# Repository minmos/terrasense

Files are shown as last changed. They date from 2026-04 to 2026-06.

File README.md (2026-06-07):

### Quick Overview
* **`firmware`**: contains the esp-idf firmware running on the esp32c6
* **`cad`**: contains the CAD files for the case housing the sockets, the 12V PSU, the relais/hv pcb, and an extension for that box housing the main pcb
* **`pcb`**: contains the KiCad files for the relais/hv pcb as well as the main pcb

### DEMO
Here is a quick demo video of our Terrasense implementation in action:

https://github.com/user-attachments/assets/7964f494-83c7-4bb1-9dd9-c3dd94d3becd

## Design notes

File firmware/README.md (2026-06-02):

# TerraSense

TerraSense is a smart-terrarium controller built on the ESP32-C6. It provides Home Assistant integration via MQTT to control the environment.

---

## Hardware Requirements/Features
* **Home Assistant Integration:** Uses MQTT Auto-Discovery for all peripherals for Home Assistant integration.
* **Custom PCB:** We used a custom PCB to keep everything clean
* **Sensor Support:**
  * **I²C:** SHT35 series (Temperature & Humidity) via multiplexer(TCA9548A).
  * **OneWire:** DS18B20.
  * **Binary:** Binary liquid level sensor(XKC-Y25-NPN).
* **Actuator Support:**
  * **GPIO:** GPIO relays and Solid State Relays (SSR) for heaters, lights, and misting pumps.
  * **Fans:** supporting 3 and 4 pin fans

---

## Wiring & Pinout

The hardware configuration as defined in `sys_config.h`. 

| Interface | Component / Name | ESP32-C6 Pin | Notes |
| :--- | :--- | :--- | :--- |
| **I²C Bus** | SDA / SCL | GPIO 5 / GPIO 6 | up to 6 SHT35 sensors supported by I²C Mux |
| **OneWire** | DS18B20 Probe | GPIO 4 | up to 8 DS18B20 sensors |
| **Binary** | Liquid Level Sensor | GPIO 11 | - |
| **GPIO Output** | 4 230V Relais(one SSR) | GPIO 7/0/1/10 | - |
| **Fan** | either MOSFET or PWM | GPIO 18-23 | two fan connectors on pcb |

*(Note: Every pin assignment, default state, and active-high/low logic can be customized in `sys_config.h`.)*

---

## Installation & Setup

### 1. Prerequisites
Ensure you have the [ESP-IDF framework](https://docs.espressif.com/projects/esp-idf/en/latest/esp32/get-started/) installed and configured on your machine.

### 2. Setup
Depending on where your ESP-IDF is installed run the following to activate ESP-IDF environment:
```bash
. $HOME/.espressif/tools/activate_idf_v6.0.sh
```
Before touching any configrations, we need to set network and MQTT broker specifics by running the following command in the root dir of our project:
```bash
idf.py menuconfig
```
### 3. Configuration
Before compiling, open `/components/sys_config/include/sys_config.h` to define the specific setup.
* **MQTT Topics:** Set `MQTT_DOMAIN_PREFIX` and `TERRARIUM_ID` which are used by macros for the topics.
* **Enable/Disable Hardware:** See the [Hardware Configuration](#hardware-configuration) section.
* **Logic Implementation:** `components/app_logic/app_logic.c` is used to define the control logic.

### 4. Build and Flash
Run the standard ESP-IDF commands to compile and flash to your board(either through terminal with `idf.py` commands or through VsCode buttons).

---

## OTA Update Support

The device supports OTA updates triggered via MQTT by publishing the location of the new binary to `<your_mqtt_base_topic>/cmd/update`.

### To locally test OTA updates

Build the project normally. Navigate to the build folder and start a temporary HTTP server(here just a tiny ruby server available under localhost:8070):

```bash
cd build
ruby -run -e httpd . -p 8070
```
The payload then looks like this:
```text
http://<your_ip>:8070/firmware.bin
```

# Hardware Configuration

Hardware and pin configurations are defined in `components/sys_config/include/sys_config.h`. We provide struct for all configurable peripherals of this project which are explained in more detail.
To keep MQTT topics somewhat consistent, we have define an MQTT scheme in `components/sys_config/mqtt_namingscheme.md`. One only has to define `MQTT_DOMAIN_PREFIX`, `TERRARIUM_ID` and the respective sensor and actuator structs. Everything else is handled by the implementation.

> If one wishes to change or extend the MQTT autodiscovery logic, one could define it through `components/app_logic/app_logic.c` and `components/net_mqtt/hass_discovery.c`.
---

## One-Wire Bus (DS18B20)
- GPIO Configuration `ONEWIRE_BUS_GPIO` defines the GPIO used for One-Wire sensors such as DS18B20 temperature sensors.
- Add DS18B20 sensors with unique mqtt device ID and unique ROM address
```c
static const ds18b20_target_t HARDWARE_DS18B20_CONFIG[] = {
    {
        .name = "Temporary DS18B20 Sensor",
        .mqtt_device_id = "ds18b20_temporaryplaceholder",
        .rom_address = 0x133C6CF64930E728
    },
};
```
>We also provide a custom ESP-IDF project for discovering one-wire DS18B20 sensors to find the addresses.

---

## I²C Bus (SHT35)
- GPIO Configuration `I2C_SDA_GPIO` and `I2C_SCL_GPIO` defines the GPIO pins used for the I²C bus
- Add SHT35 sensors using a channel(0-5 are supported):
```c
static const sht3x_target_t HARDWARE_SHT3X_CONFIG[] = {
    {
        .name = "SHT35 Test Sensor",
        .mqtt_device_id = "sht35_ambient_test",
        .mux_channel = 0
    },
};
```

---

##  Binary Sensor (XKC-Y25-NPN)
- GPIO Configuration `.gpio_pin` defines the GPIO used for the binary liquid level sensor.
- The PCB currently supports only one binary sensor, however one could extend the list
```c
static const binary_sensor_target_t HARDWARE_BINARY_CONFIG[] = {
    { .name = "Tank Empty", .mqtt_device_id = "liquid_level_sensor", .gpio_pin = BINARY_SENSOR_GPIO, .invert_logic = true },
};
```

---

##  Hardware Switch (3 normal relais, one SSR)
- GPIO Configuration `.gpio_pin` defines the GPIO used for the binary liquid level sensor.
```c
static const switch_target_t HARDWARE_SWITCH_CONFIG[] = {
    { .name = "Lights", .mqtt_device_id = "lights", .gpio_pin = RELAY_0_GPIO, .active_high = true, .default_state = false },
};
```

---

##  Fans (3 and 4 pin fans)
- GPIO Configuration `.power_pin` defines the GPIO used to control the power for a 3 pin fan over a MOSFET
- GPIO Configuration `.pwm_pin` defines the GPIO used for PWM control of a 4 pin fan.
- `.tach_pin` only got us meaningful results on 4 pin fans, therefore `FAN_UNUSED_PIN` for 3 pin fans.
```c
static const fan_target_t HARDWARE_FAN_CONFIG[] = {
    { .name = "Fan", .mqtt_device_id = "fan", .power_pin = FAN0_POWER_PIN, .tach_pin = FAN0_TACH_PIN, .pwm_pin = FAN0_PWN_PIN, .is_4pin = true },
    { .name = "temp three Fan", .mqtt_device_id = "fan_three", .power_pin = FAN0_POWER_PIN, .tach_pin = FAN_UNUSED_PIN, .pwm_pin = FAN_UNUSED_PIN, .is_4pin = false },
};
```

---

##  Numbers for Home Assistant
- This struct could be used to define target temperatures which could be changed and controlled form the Home Assistant UI.
```c
static const number_target_t HARDWARE_NUMBER_CONFIG[] = {
    { 
        .name = "Target Temperature Day", 
        .mqtt_device_id = "target_temp_day", 
        .min_val = 20.0, 
        .max_val = 32.0, 
        .step = 0.5, 
        .default_val = 28.0, 
        .mode = "slider"
    }
};

```

# ESP32-C6 Infos

[ESP32-C6 pinout information](https://docs.waveshare.com/ESP32-C6-DEV-KIT-N8/ "esp32-c6-pinout")

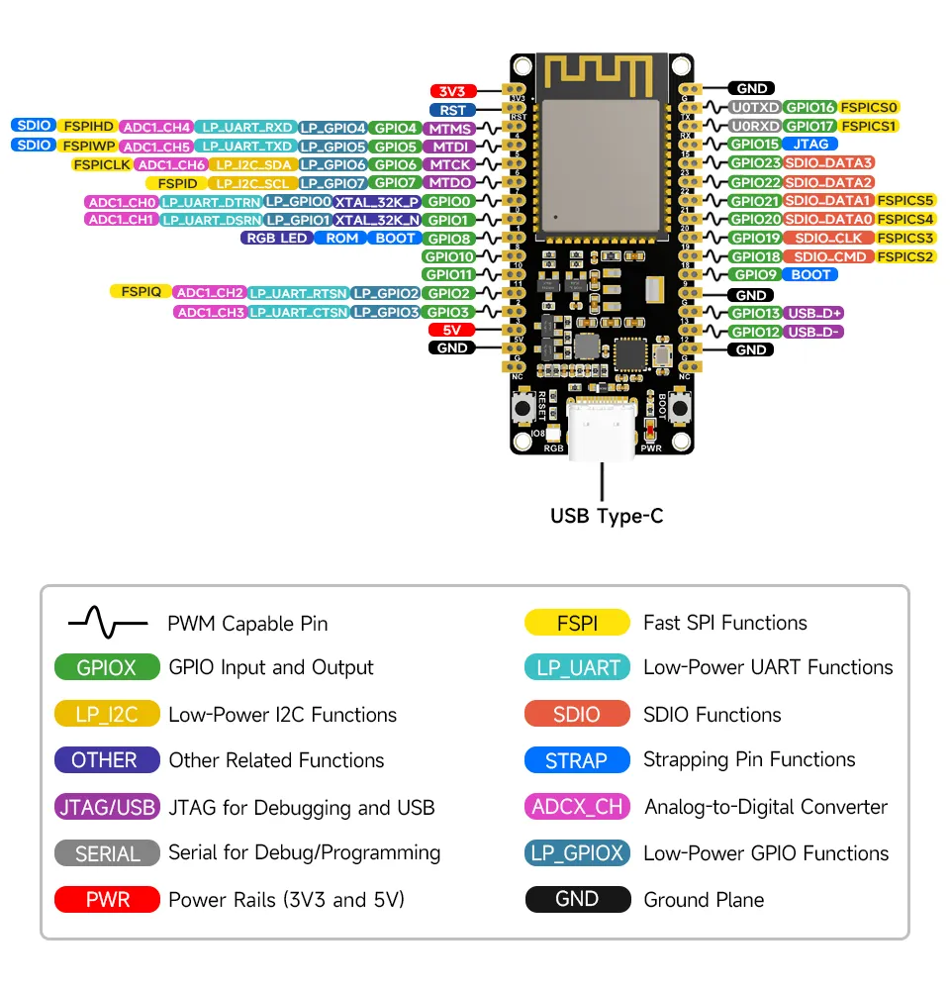
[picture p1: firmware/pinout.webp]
Pinout diagram


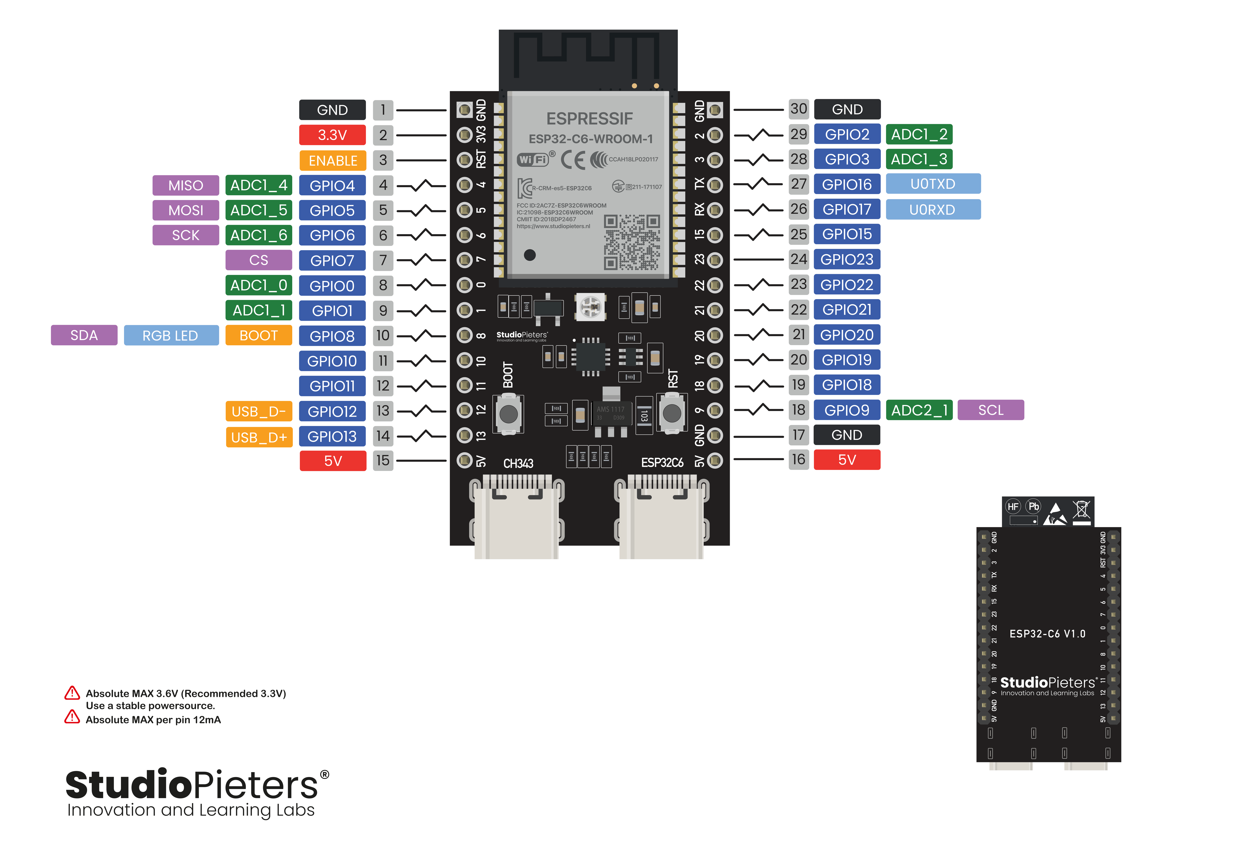
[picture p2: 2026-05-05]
firmware/pinout.png

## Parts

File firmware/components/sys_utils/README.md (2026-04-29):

set led background tasks via sys_led_set_state, booting is yellow blinking intervall 500ms
error case is red iwth 200ms interval

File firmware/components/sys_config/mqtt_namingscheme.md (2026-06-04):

# MQTT Topic Hierarchy Proposal

This document defines a structured MQTT topic scheme for managing multiple terrasense, enabling consistent auto-discovery (e.g., Home Assistant MQTT discovery), clear separation of state vs. command topics, and support for various sensor/actuator types.

## Core Structure

Basic pattern:  
`terrasense/<terrarium_id>/<component_type>/<device_id>/<attribute>`

- **terrasense** – fixed domain prefix, equivalent to `MQTT_BASE_TOPIC` in `sys_config.h`
- **<terrarium_id>** – unique identifier per terrarium (e.g., `rainforest_01`, `desert_03`)  
- **<component_type>** – one of: `sensor`, `switch`, `number`, `fan`, `binary_sensor`  
- **<device_id>** – logical name of the physical device + unique suffix/description, concatinated with `_` (e.g., `ds18b20_toprightcorner`, `ssr_heatinglamp`)  
- **<attribute>** – e.g., `state`, `command`, `temperature`, `humidity`, `speed`

## Consistency Rules Overview
TODO need to fix rules for multiple attributes for a single sensor
| Element | Rule |
|---|---|
| **No spaces** | Use underscores `_` |
| **Lowercase only** | `rainforest_01` |
| **Device ID** | `<logical_name>_<unique_suffix>` |
| **Component type** | Use HA MQTT component names, [MQTT components list](https://www.home-assistant.io/integrations/mqtt/#configuration-via-mqtt-discovery "www.home-assistant.io/integrations/mqtt/#configuration-via-mqtt-discovery")|

## Discovery Topic Pattern

For Home Assistant MQTT auto-discovery, use:

`homeassistant/<component_type>/<object_id>/config`

`object_id` is a concatination with `-` of `terrasense`, `terrarium_id` and `device_id`

Example:  
`homeassistant/sensor/terrasense-rainforest_01-ssr_heatinglamp/config`

Payload contains `state_topic`, `command_topic` (if applicable), `device`, `unique_id` (`unique_id` THE SAME AS `object_id`), etc.

## State vs. Command Topics

| Topic type | Pattern | Example |
|---|---|---|
| State (read-only) | `terrasense/<terrarium_id>/<component_type>/<device_id>/state` | `terrasense/rainforest_01/sensor/ambient_sht35/state` |
| Command (write) | `terrasense/<terrarium_id>/<component_type>/<device_id>/command` | `terrasense/rainforest_01/switch/misting_ssr/command` |

**Rule:**  
- `state` → device publishes measurements/status
- `command` → controller publishes actions

## Device-Specific Examples
### Sensors

#### **OneWire – DS18B20** (temperature)  
- Component: `sensor`  
- Device ID: `ds18b20_<serial_suffix>`  
- Topics:  
  - State: `terrasense/rainforest_01/sensor/ds18b20_toprightcorner/state` (payload: `{"temperature": 25.3}`)  
  - Auto-discovery: `homeassistant/sensor/terrasense-rainforest_01-_ds18b20_toprightcorner/config`

#### **I2C – SHT35 (temperature + humidity)**  
Treat as two separate sensors or one device with multiple state topics.  
Recommended: separate devices for clarity.  

- Temp device: `sht35_temperature`  
- Humidity device: `sht35_humidity`  

State topics:  
`terrasense/rainforest_01/sensor/sht35_bottom_temperature/state` → `{"temperature": 23.5}`  
`terrasense/rainforest_01/sensor/sht35_bottom_humidity/state` → `{"humidity": 58.2}`  

*(Optional: single device with `state` publishing `{"temperature": x, "humidity": y}` – less granular but simpler.)*

#### **Simple I/O – XKC-Y25 (water detection)**  
Component: `binary_sensor`  
Device ID: `water_detector_suffix`  
State topic: `terrasense/rainforest_01/binary_sensor/water_detector_suffix/state` (payload: `{"water_detected": true}` or just `1`/`0`)

### Actuators

#### **Simple I/O – SSR (Misting, Lights, Heating)**  
Component: `switch` 
Device ID: `ssr_misting`, `ssr_lights`, `ssr_heater`  
Command topic: `terrasense/rainforest_01/switch/ssr_misting/command` (payload: `ON`/`OFF`)  

#### **Fan Control – 3‑pin & 4‑pin fans**  
For 3‑pin (voltage control) / 4‑pin (PWM) – both benefit from separate speed control.  

Component: `fan` (Home Assistant supports fan component)  
Device ID: `fanpwm_1`  
Command topic: `terrasense/rainforest_01/fan/fanpwm_1/command`  
Payload: `ON`/`OFF` or `{"speed": 128}` (0–255)  
State topic: `terrasense/rainforest_01/fan/fanpwm_1/state`

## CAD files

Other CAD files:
cad/Box.ipt
cad/Box_Assembly.iam
cad/Double_Steckdose.ipt
cad/Kaltstecker.ipt
cad/LV_Deckel.ipt
cad/PSU.ipt
cad/Steckdose.ipt
cad/Steckdosen_Block.ipt
cad/hv_pcb/high_volt_switch_PCB.ipt
cad/hv_pcb/hv_pcb.iam
cad/main_pcb/main_pcb.iam
cad/main_pcb/terrasense_PCB.ipt

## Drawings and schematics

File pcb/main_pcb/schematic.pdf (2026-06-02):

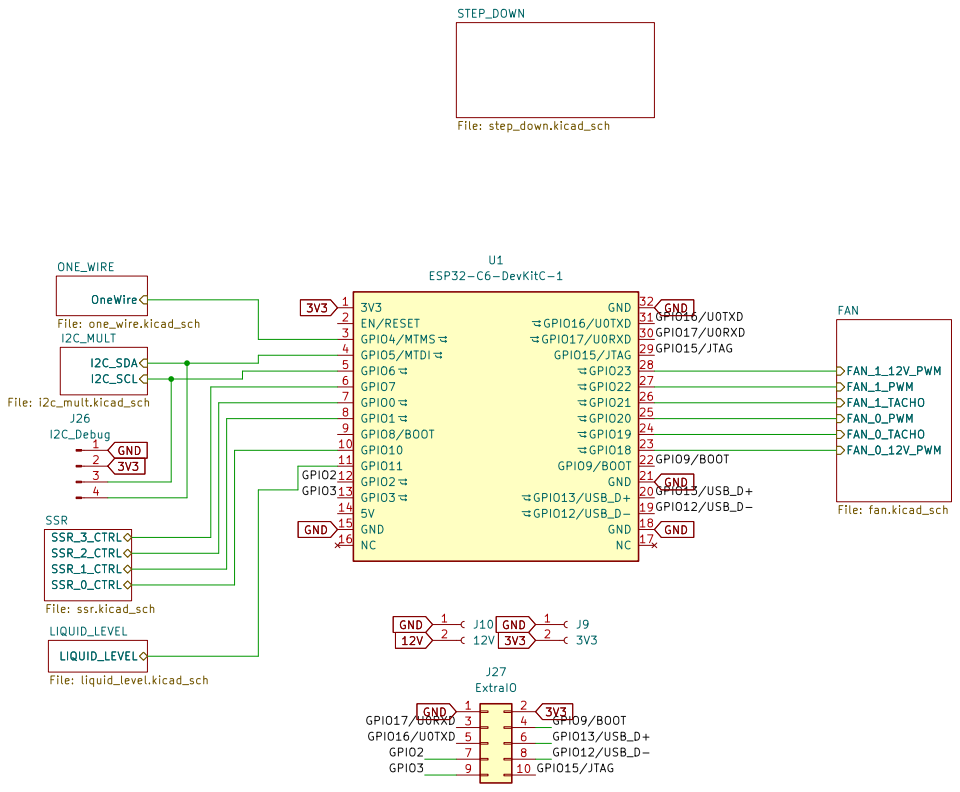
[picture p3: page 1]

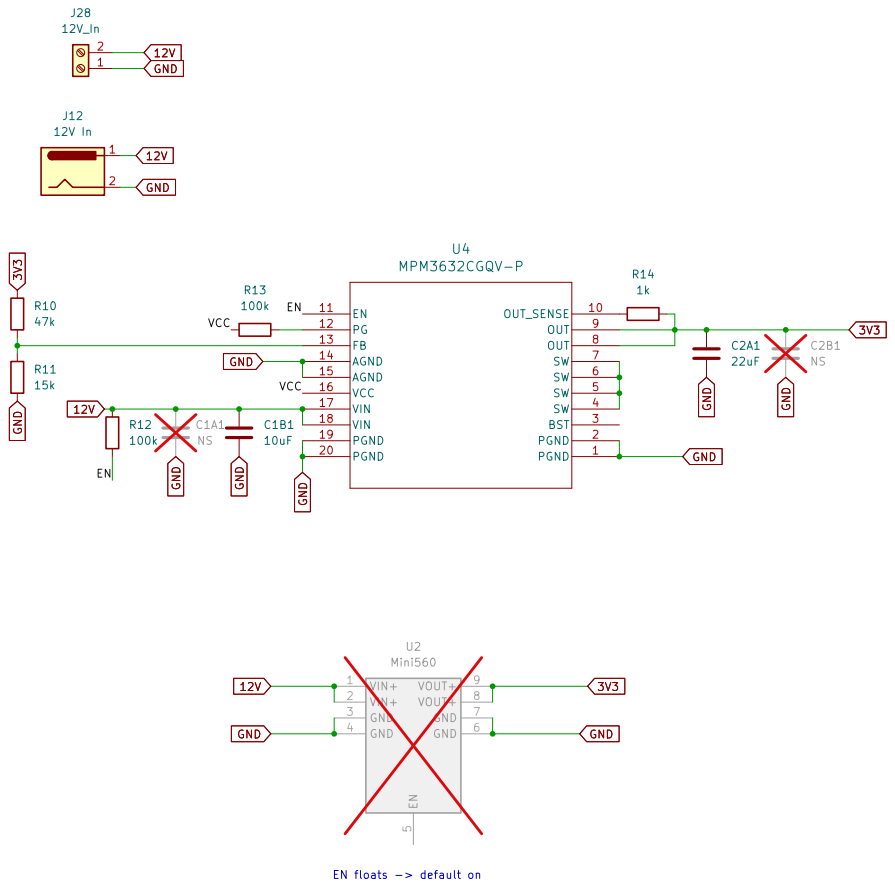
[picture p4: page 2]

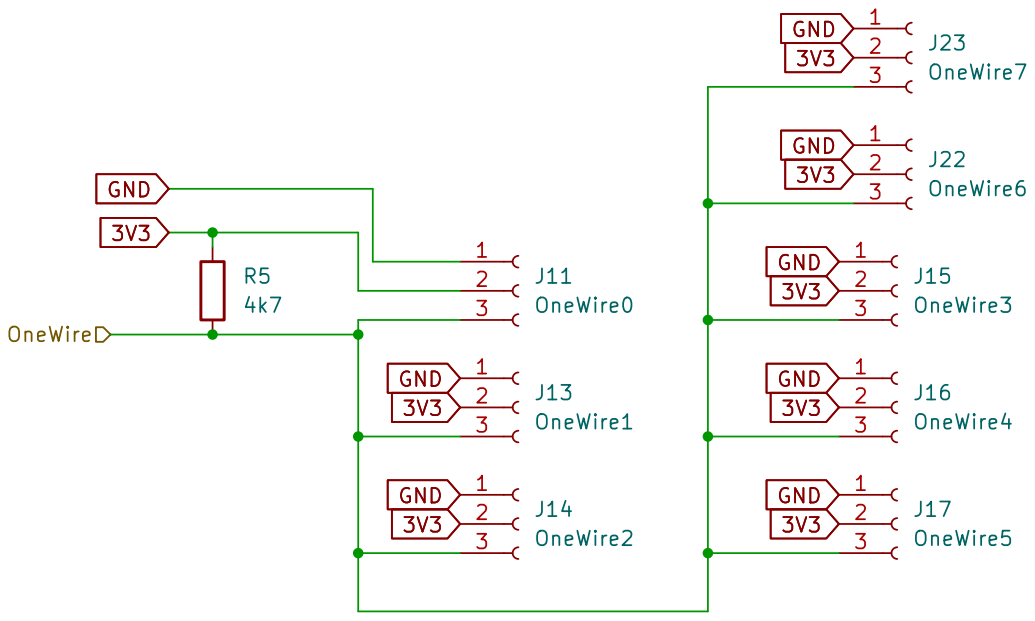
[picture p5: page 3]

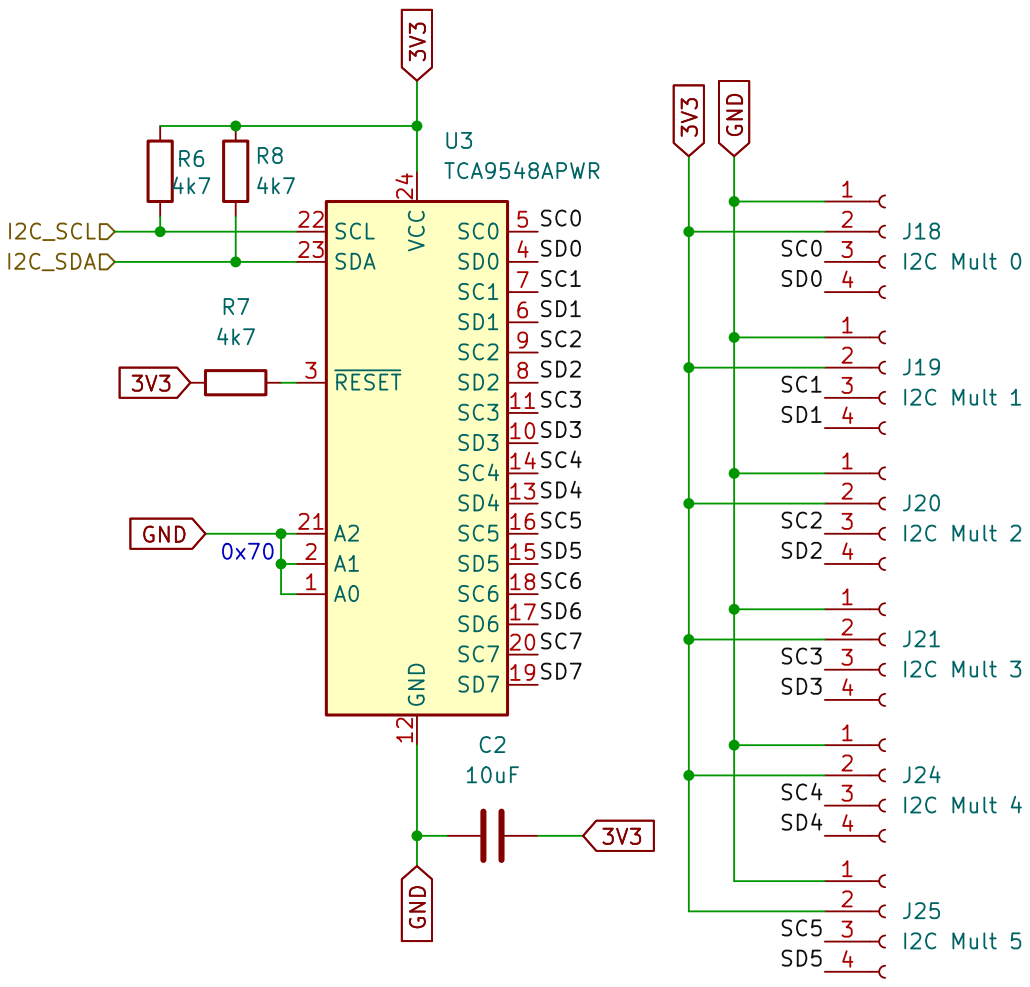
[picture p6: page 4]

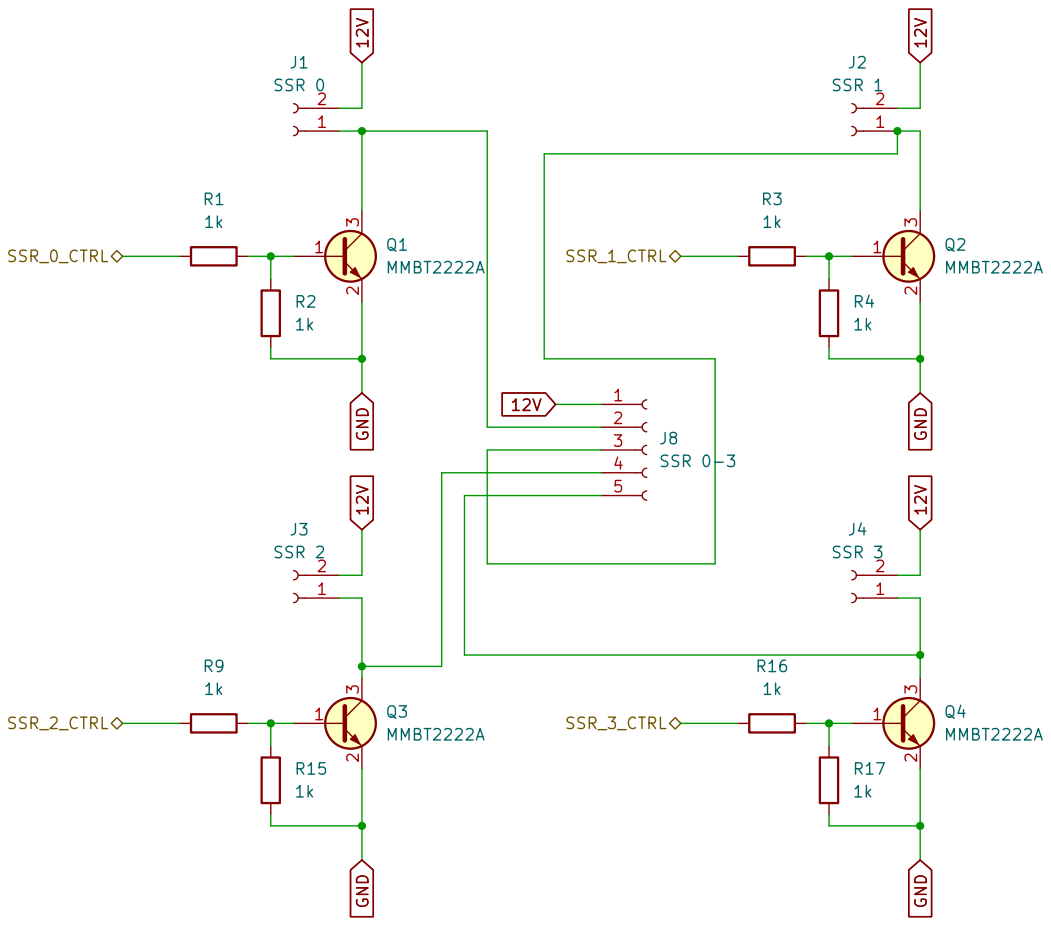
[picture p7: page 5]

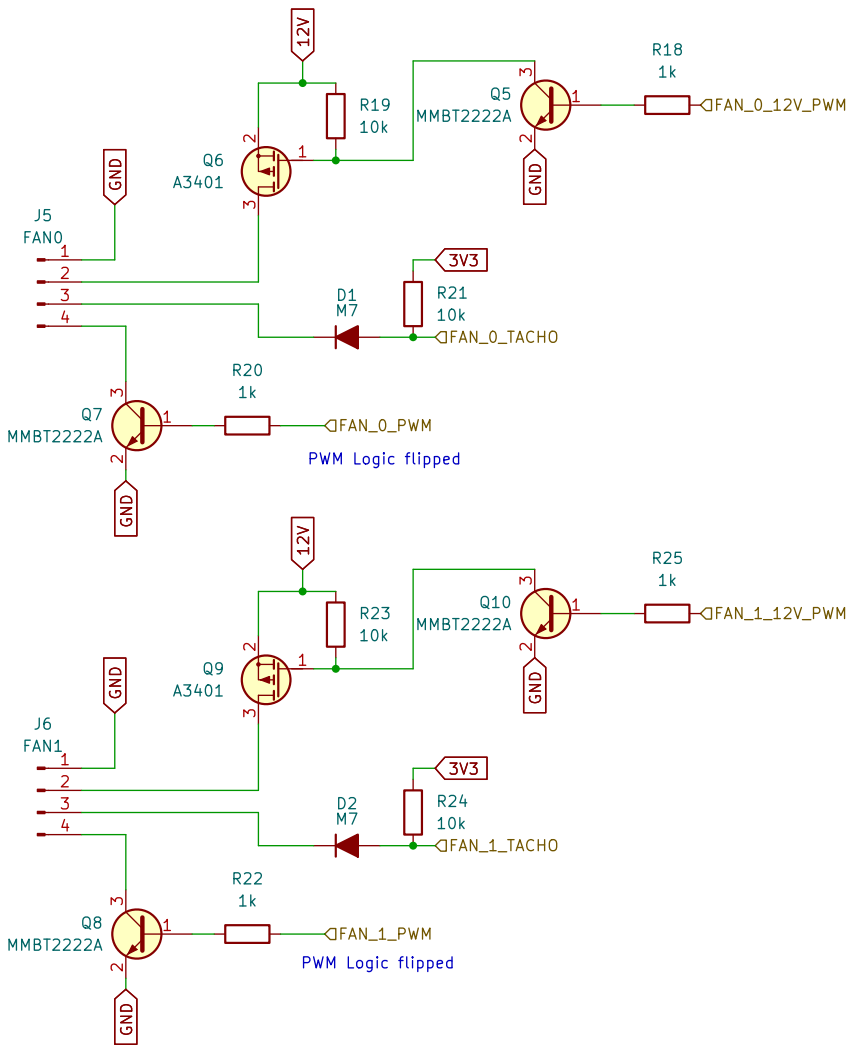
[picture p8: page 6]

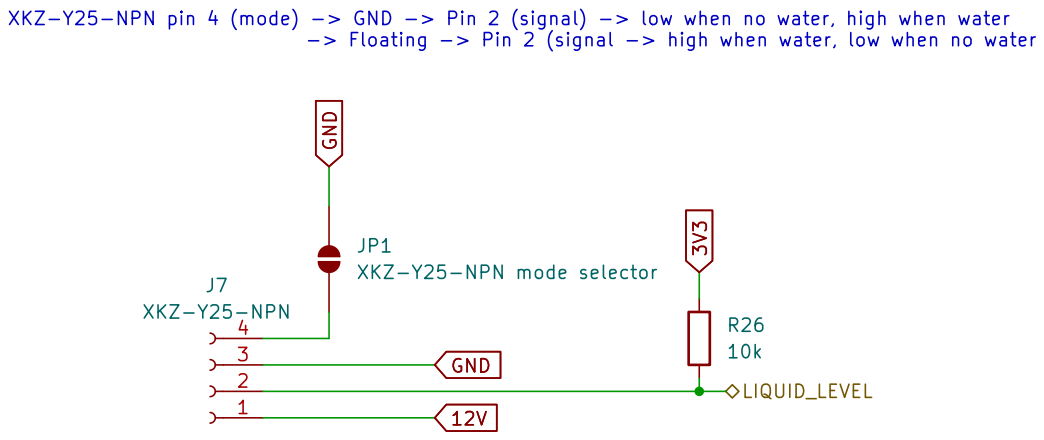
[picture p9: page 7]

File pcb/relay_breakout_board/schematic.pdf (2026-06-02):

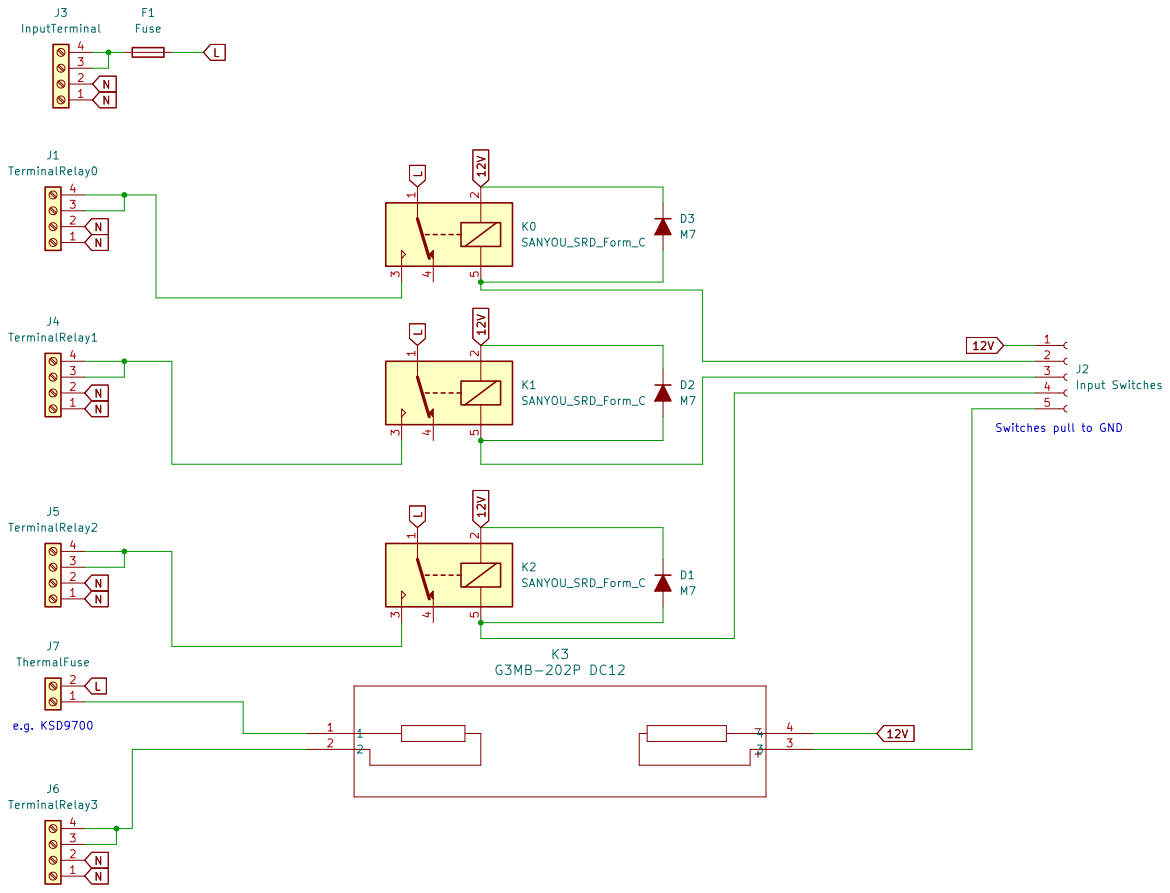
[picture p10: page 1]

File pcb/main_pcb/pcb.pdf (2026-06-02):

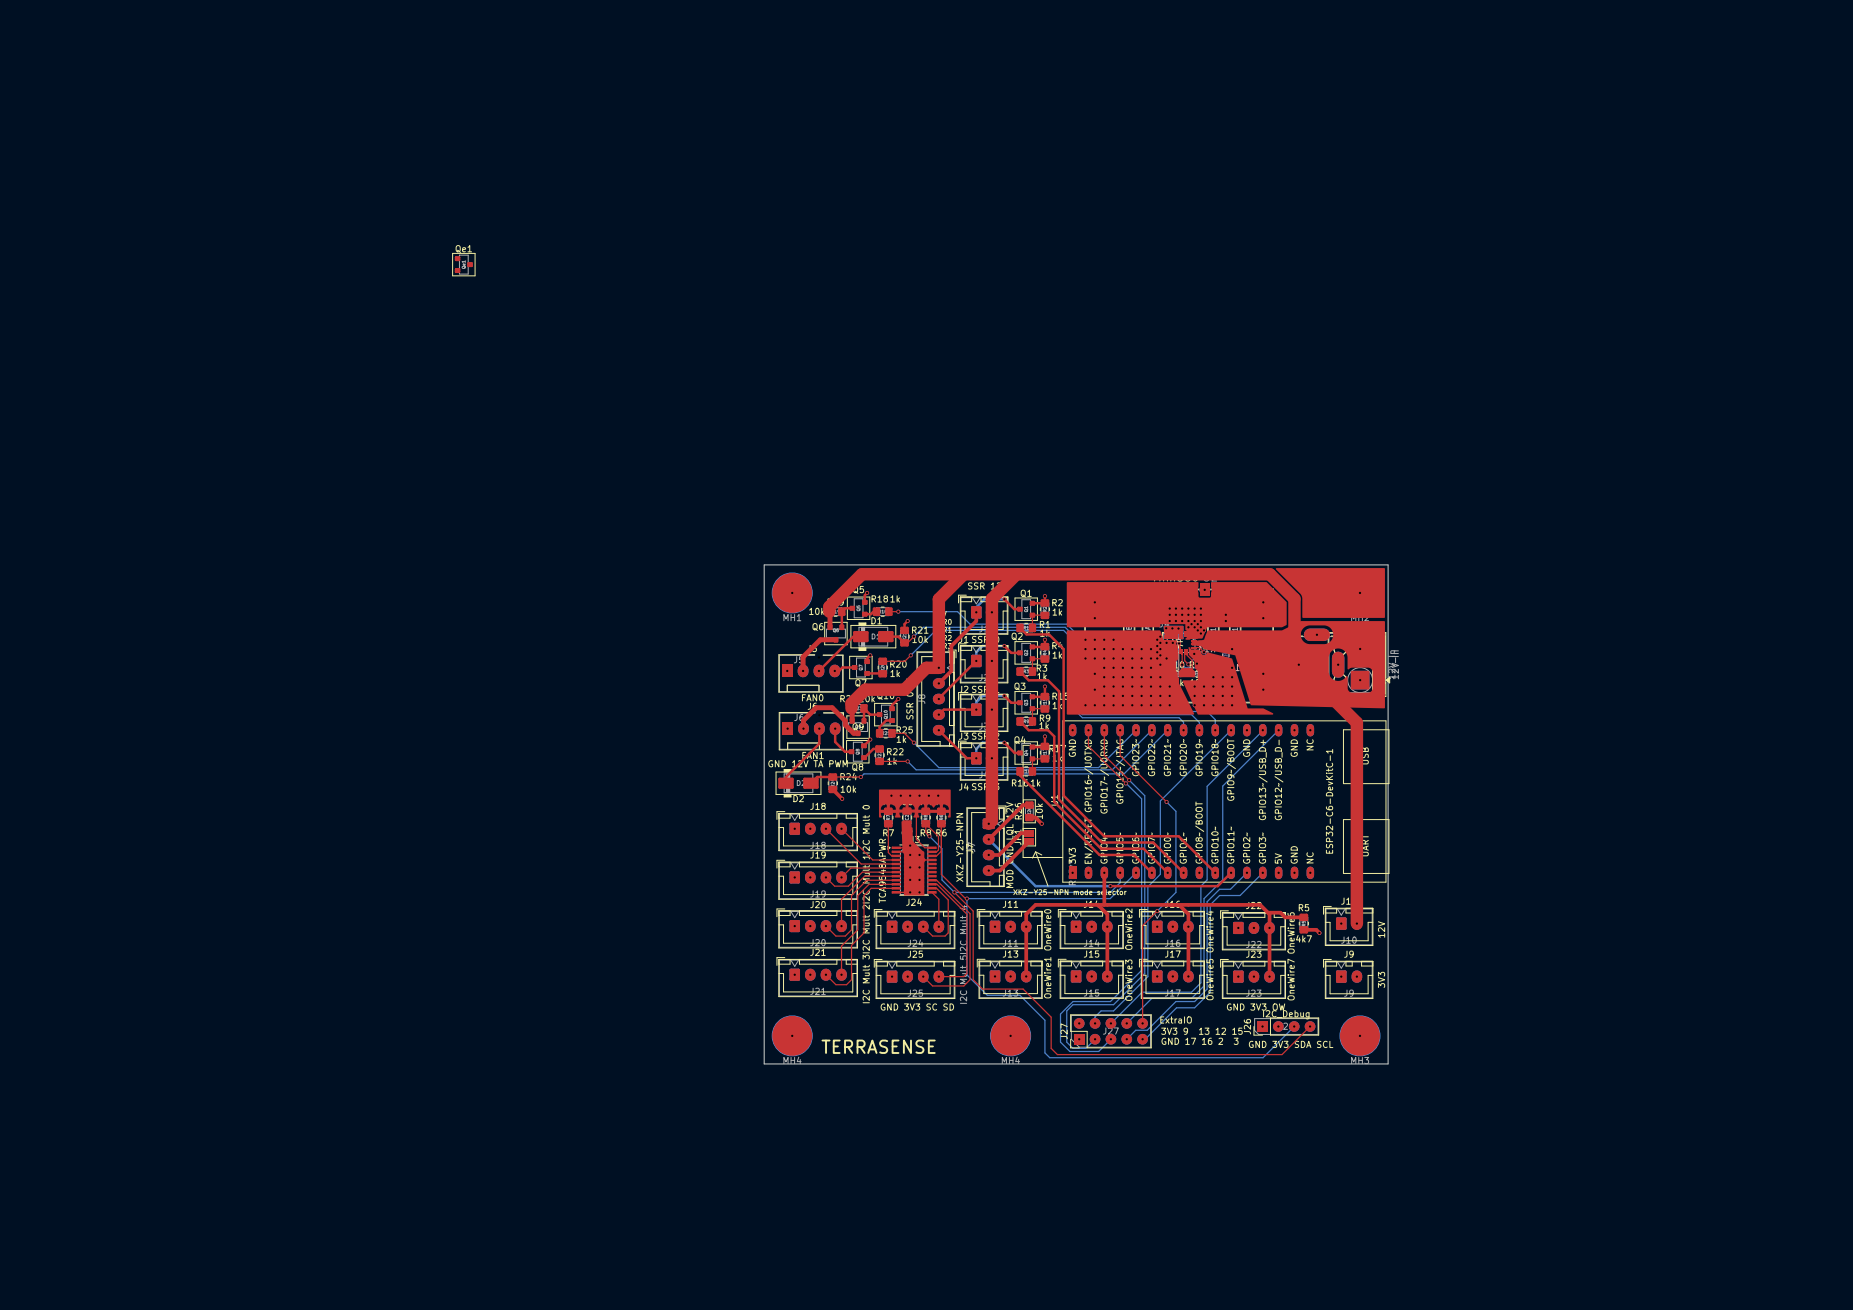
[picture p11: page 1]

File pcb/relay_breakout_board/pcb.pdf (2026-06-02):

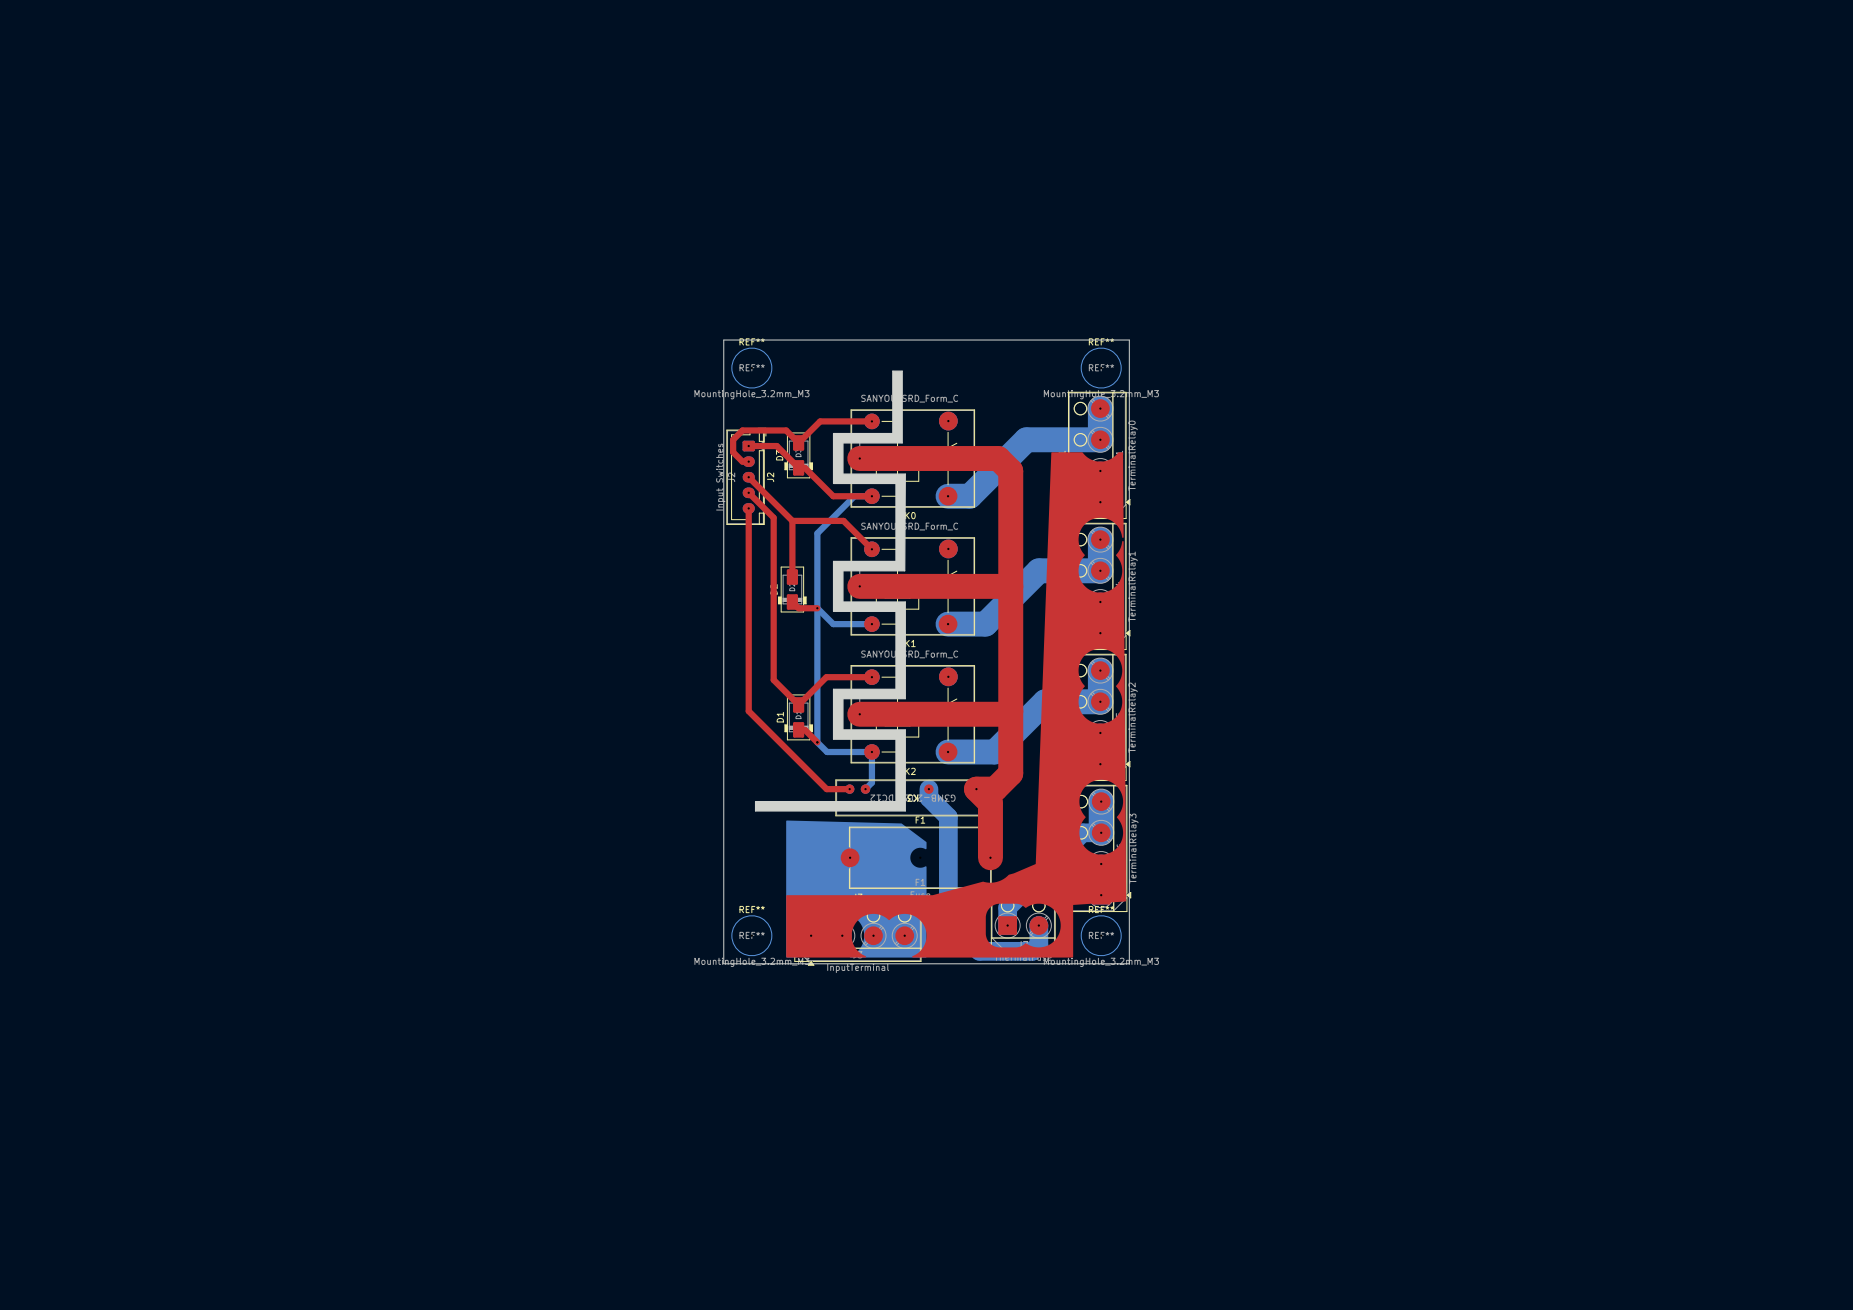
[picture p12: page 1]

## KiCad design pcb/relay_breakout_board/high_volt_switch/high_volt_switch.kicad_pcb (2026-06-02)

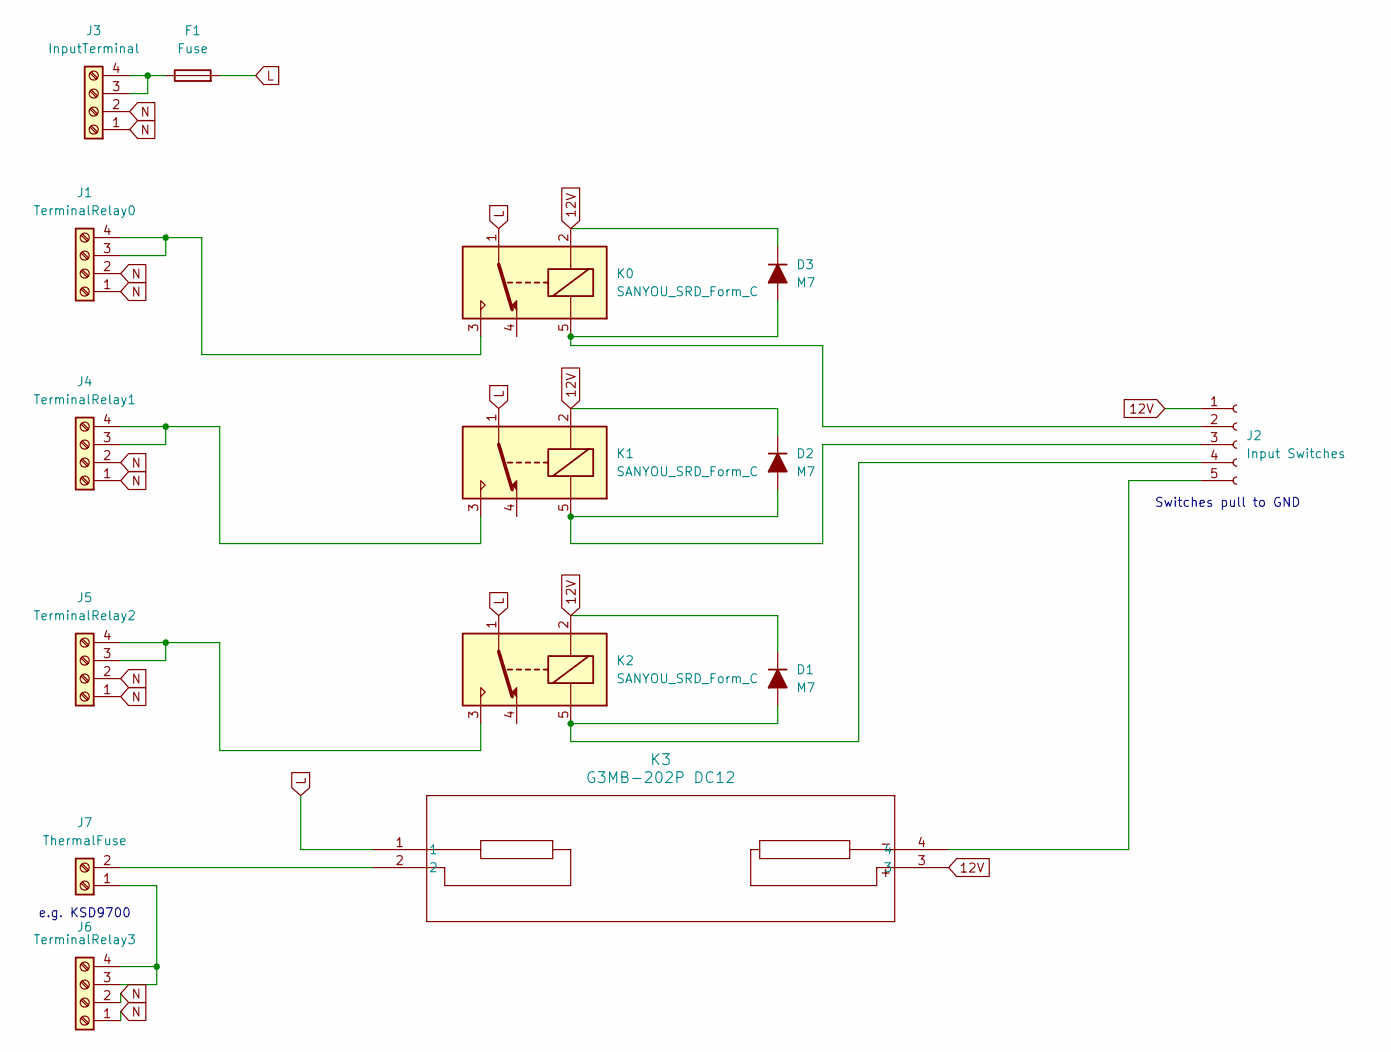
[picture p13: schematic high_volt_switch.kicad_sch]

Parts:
D1, D2, D3: M7; D_SMA
F1: Fuse; Fuseholder_Cylinder-5x20mm_Schurter_0031_8201_Horizontal_Op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
J1: TerminalRelay0; Altech_AK100_1x04_P5.00mm
J2: Input Switches; JST_XH_B5B-XH-A_1x05_P2.50mm_Vertical
J3: InputTerminal; Altech_AK100_1x04_P5.00mm
J4: TerminalRelay1; Altech_AK100_1x04_P5.00mm
J5: TerminalRelay2; Altech_AK100_1x04_P5.00mm
J6: TerminalRelay3; Altech_AK100_1x04_P5.00mm
J7: ThermalFuse; Altech_AK100_1x02_P5.00mm
K0, K1, K2: SANYOU_SRD_Form_C; Relay_SPDT_SANYOU_SRD_Series_Form_C
K3: G3MB-202P DC12; G3MB-202P DC5_OMR

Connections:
12V: D1.1 (K), D2.1 (K), D3.1 (K), J2.1, K0.2, K1.2, K2.2, K3.3
L: F1.2, K0.1, K1.1, K2.1, K3.1
N: J1.1, J1.2, J3.1, J3.2, J4.1, J4.2, J5.1, J5.2, J6.1, J6.2
unnamed: D1.2 (A), J2.4, K2.5
unnamed: D2.2 (A), J2.3, K1.5
unnamed: D3.2 (A), J2.2, K0.5
unnamed: J1.3, J1.4, K0.3
unnamed: J2.5, K3.4
unnamed: F1.1, J3.3, J3.4
unnamed: J4.3, J4.4, K1.3
unnamed: J5.3, J5.4, K2.3
unnamed: J6.3, J6.4, J7.1
unnamed: J7.2, K3.2

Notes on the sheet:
Switches pull to GND
e.g. KSD9700

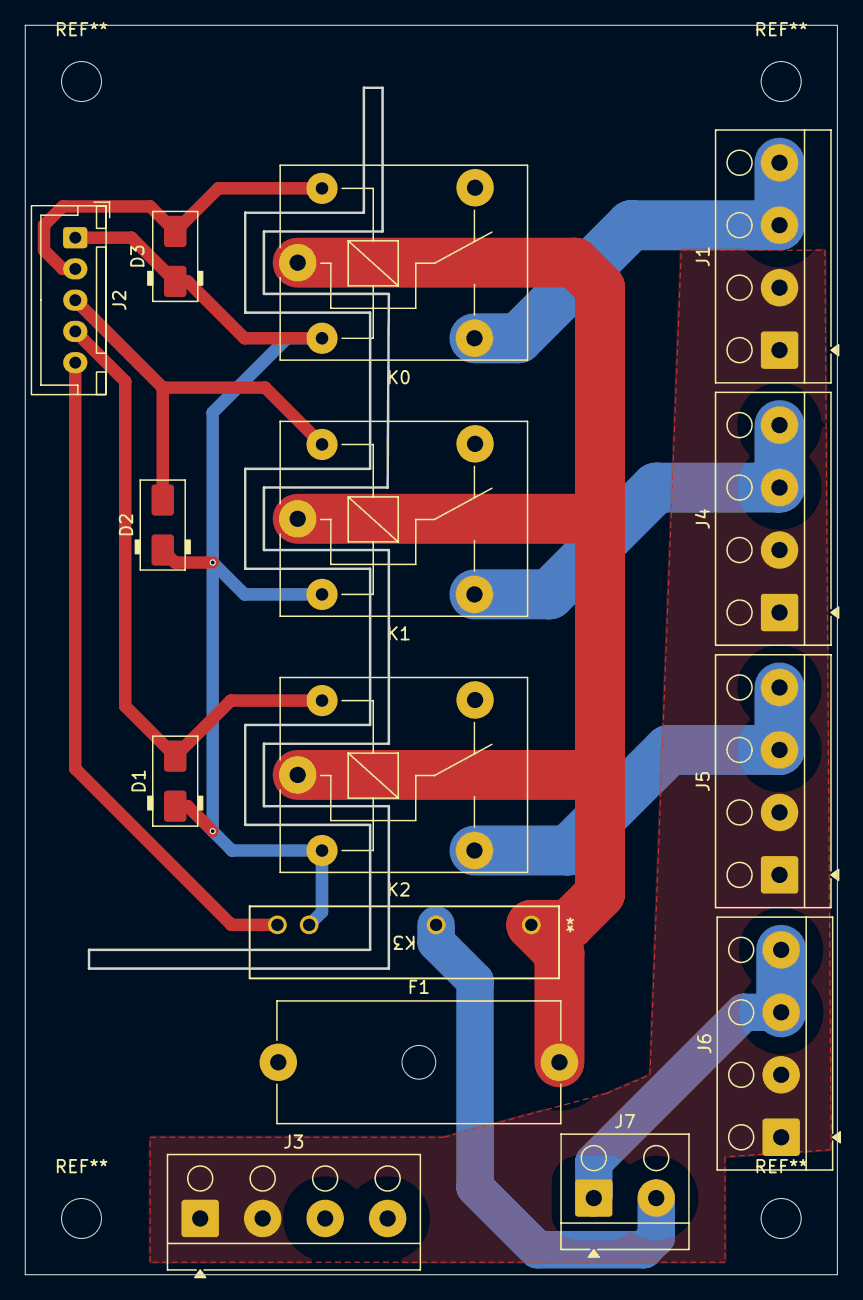
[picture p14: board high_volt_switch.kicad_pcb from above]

Board: 2 copper layers, 65.0 x 100.0 mm, 15 parts (0 on the bottom side), 13 nets.

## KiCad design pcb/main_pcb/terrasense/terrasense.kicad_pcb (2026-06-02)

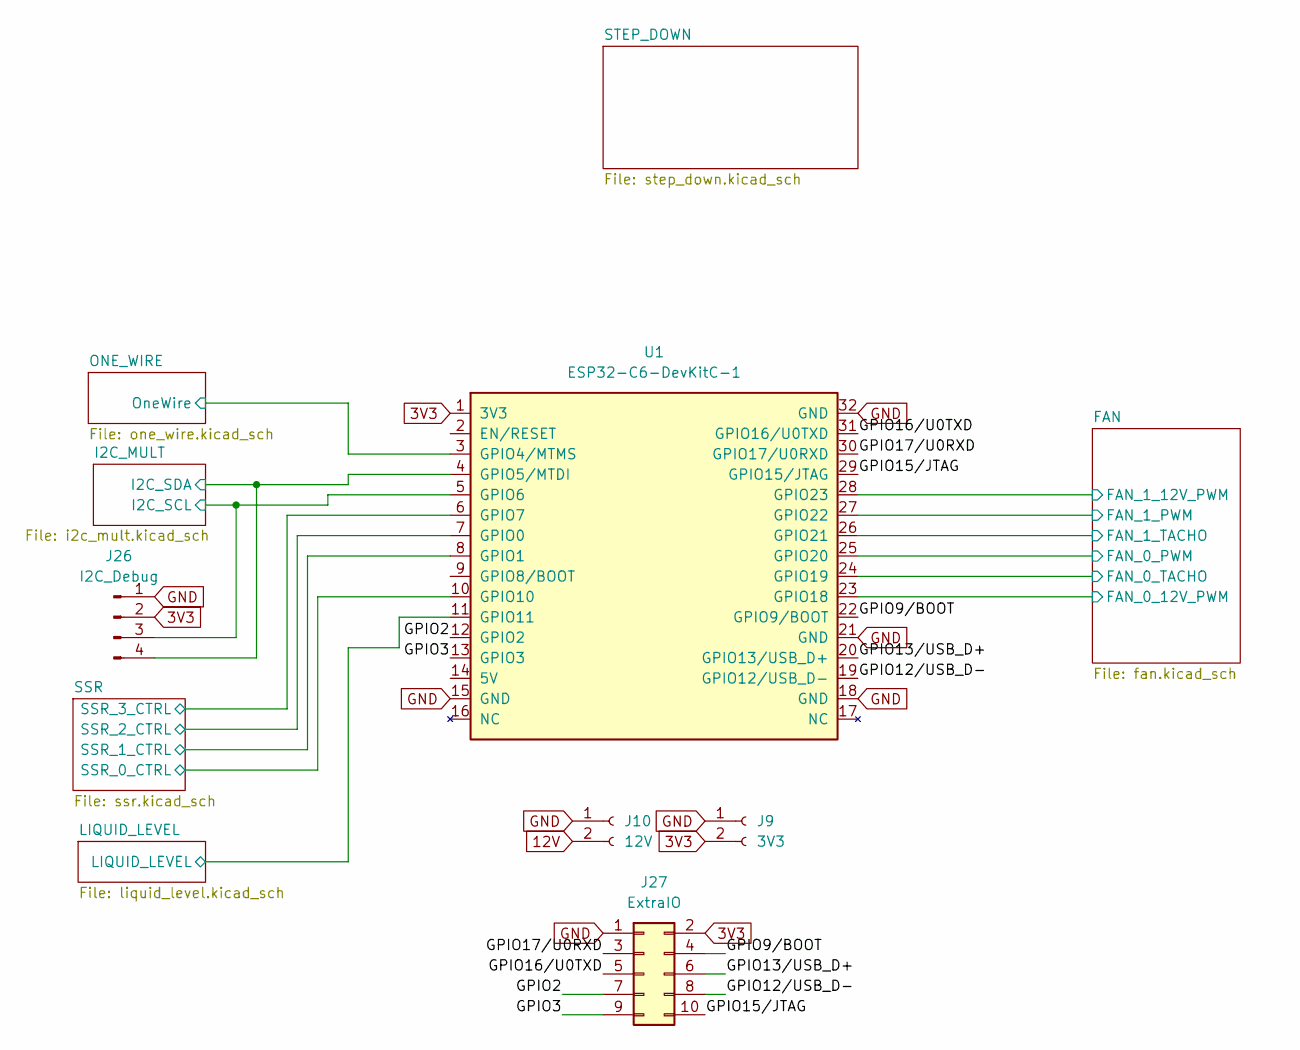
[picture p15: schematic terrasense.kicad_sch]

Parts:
J9: 3V3; JST_XH_B2B-XH-A_1x02_P2.50mm_Vertical
J10: 12V; JST_XH_B2B-XH-A_1x02_P2.50mm_Vertical
J26: I2C_Debug; PinHeader_1x04_P2.54mm_Vertical
J27: ExtraIO; PinHeader_2x05_P2.54mm_Vertical
U1: ESP32-C6-DevKitC-1

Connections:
3V3: J9.2, J26.2, J27.2, U1.1 (3V3); also elsewhere on the board
12V: J10.2; also elsewhere on the board
/FAN/FAN_0_12V_PWM: U1.23 (GPIO18); also elsewhere on the board
/FAN/FAN_0_PWM: U1.25 (GPIO20); also elsewhere on the board
/FAN/FAN_0_TACHO: U1.24 (GPIO19); also elsewhere on the board
/FAN/FAN_1_12V_PWM: U1.28 (GPIO23); also elsewhere on the board
/FAN/FAN_1_PWM: U1.27 (GPIO22); also elsewhere on the board
/FAN/FAN_1_TACHO: U1.26 (GPIO21); also elsewhere on the board
/GPIO2: J27.7, U1.12 (GPIO2)
/GPIO3: J27.9, U1.13 (GPIO3)
/GPIO9/BOOT: J27.4, U1.22 (GPIO9/BOOT)
/GPIO12/USB_D-: J27.8, U1.19 (GPIO12/USB_D-)
/GPIO13/USB_D+: J27.6, U1.20 (GPIO13/USB_D+)
/GPIO15/JTAG: J27.10, U1.29 (GPIO15/JTAG)
/GPIO16/U0TXD: J27.5, U1.31 (GPIO16/U0TXD)
/GPIO17/U0RXD: J27.3, U1.30 (GPIO17/U0RXD)
/I2C_MULT/I2C_SCL: J26.3, U1.5 (GPIO6); also elsewhere on the board
/I2C_MULT/I2C_SDA: J26.4, U1.4 (GPIO5/MTDI); also elsewhere on the board
/LIQUID_LEVEL/LIQUID_LEVEL: U1.11 (GPIO11); also elsewhere on the board
/ONE_WIRE/OneWire: U1.3 (GPIO4/MTMS); also elsewhere on the board
/SSR/SSR_0_CTRL: U1.10 (GPIO10); also elsewhere on the board
/SSR/SSR_1_CTRL: U1.8 (GPIO1); also elsewhere on the board
/SSR/SSR_2_CTRL: U1.7 (GPIO0); also elsewhere on the board
/SSR/SSR_3_CTRL: U1.6 (GPIO7); also elsewhere on the board
GND: J9.1, J10.1, J26.1, J27.1, U1.15 (GND), U1.18 (GND), U1.21 (GND), U1.32 (GND); also elsewhere on the board

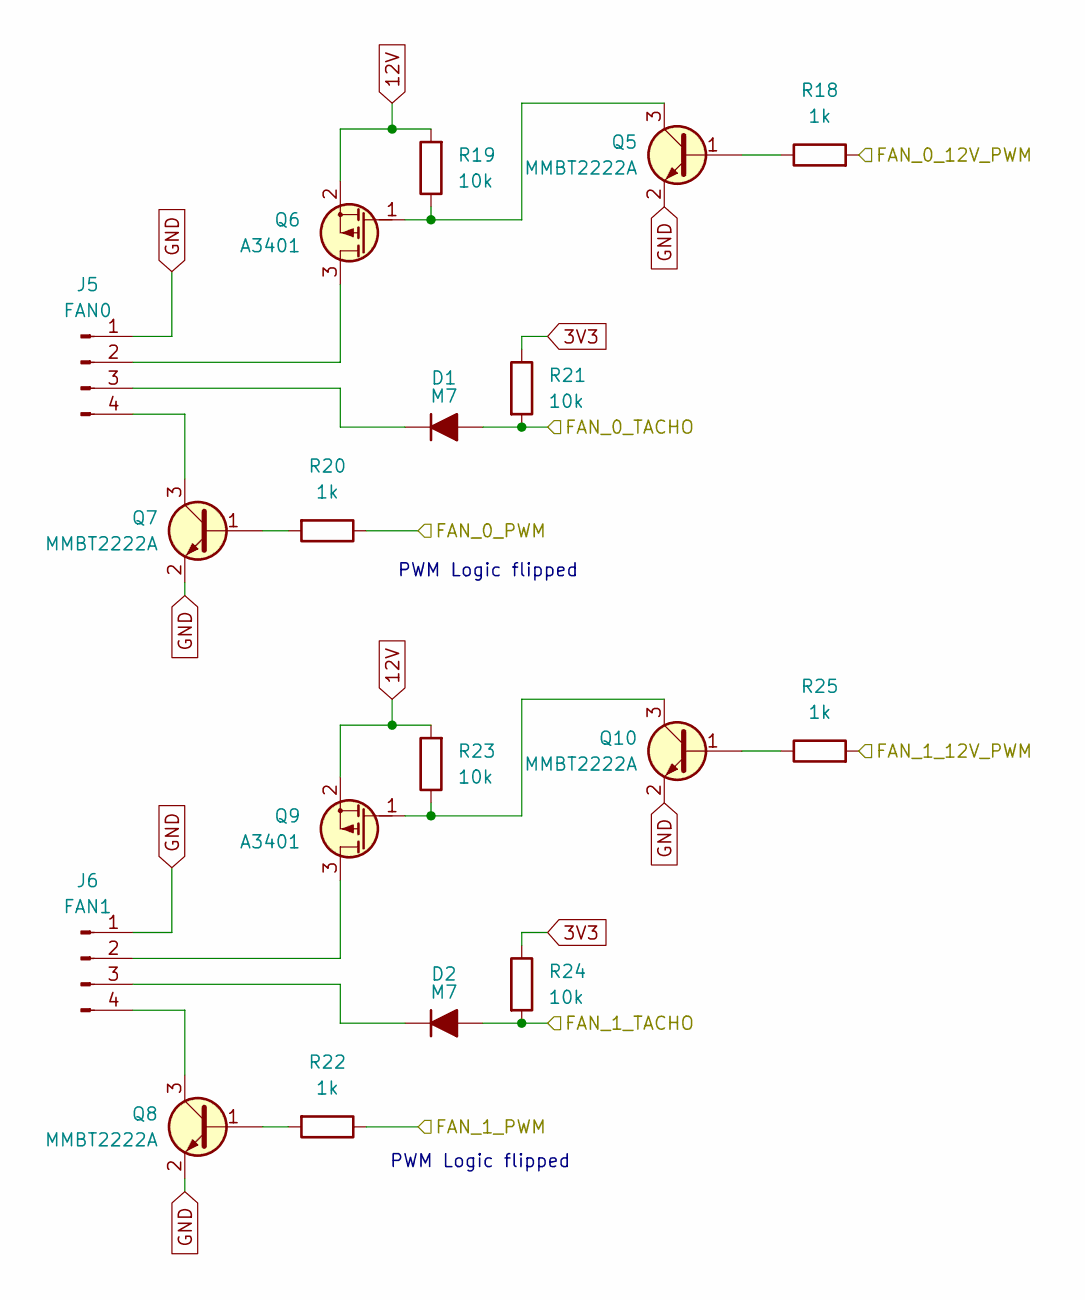
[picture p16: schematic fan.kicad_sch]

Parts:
D1, D2: M7; D_SMA
J5: FAN0; FanPinHeader_1x04_P2.54mm_Vertical
J6: FAN1; FanPinHeader_1x04_P2.54mm_Vertical
Q5, Q7, Q8, Q10: MMBT2222A; SOT-23
Q6, Q9: A3401; SOT-23
R18, R20, R22, R25: 1k; R_0805_2012Metric_Pad1.20x1.40mm_HandSolder
R19, R21, R23, R24: 10k; R_0805_2012Metric_Pad1.20x1.40mm_HandSolder

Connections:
3V3: R21.1, R24.1; also elsewhere on the board
12V: Q6.2 (S), Q9.2 (S), R19.2, R23.2; also elsewhere on the board
/FAN/FAN_0_12V_PWM: R18.2; also elsewhere on the board
/FAN/FAN_0_PWM: R20.1; also elsewhere on the board
/FAN/FAN_0_TACHO: D1.2 (A), R21.2; also elsewhere on the board
/FAN/FAN_1_12V_PWM: R25.2; also elsewhere on the board
/FAN/FAN_1_PWM: R22.1; also elsewhere on the board
/FAN/FAN_1_TACHO: D2.2 (A), R24.2; also elsewhere on the board
GND: J5.1, J6.1, Q5.2 (E), Q7.2 (E), Q8.2 (E), Q10.2 (E); also elsewhere on the board
unnamed: D1.1 (K), J5.3
unnamed: D2.1 (K), J6.3
unnamed: J5.2, Q6.3 (D)
unnamed: J5.4, Q7.3 (C)
unnamed 51: J6.2, Q9.3 (D); also elsewhere on the board
unnamed: J6.4, Q8.3 (C)
unnamed: Q5.1 (B), R18.1
unnamed: Q5.3 (C), Q6.1 (G), R19.1
unnamed: Q7.1 (B), R20.2
unnamed: Q8.1 (B), R22.2
unnamed: Q10.1 (B), R25.1
unnamed 63: Q9.1 (G), Q10.3 (C), R23.1; also elsewhere on the board

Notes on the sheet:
PWM Logic flipped

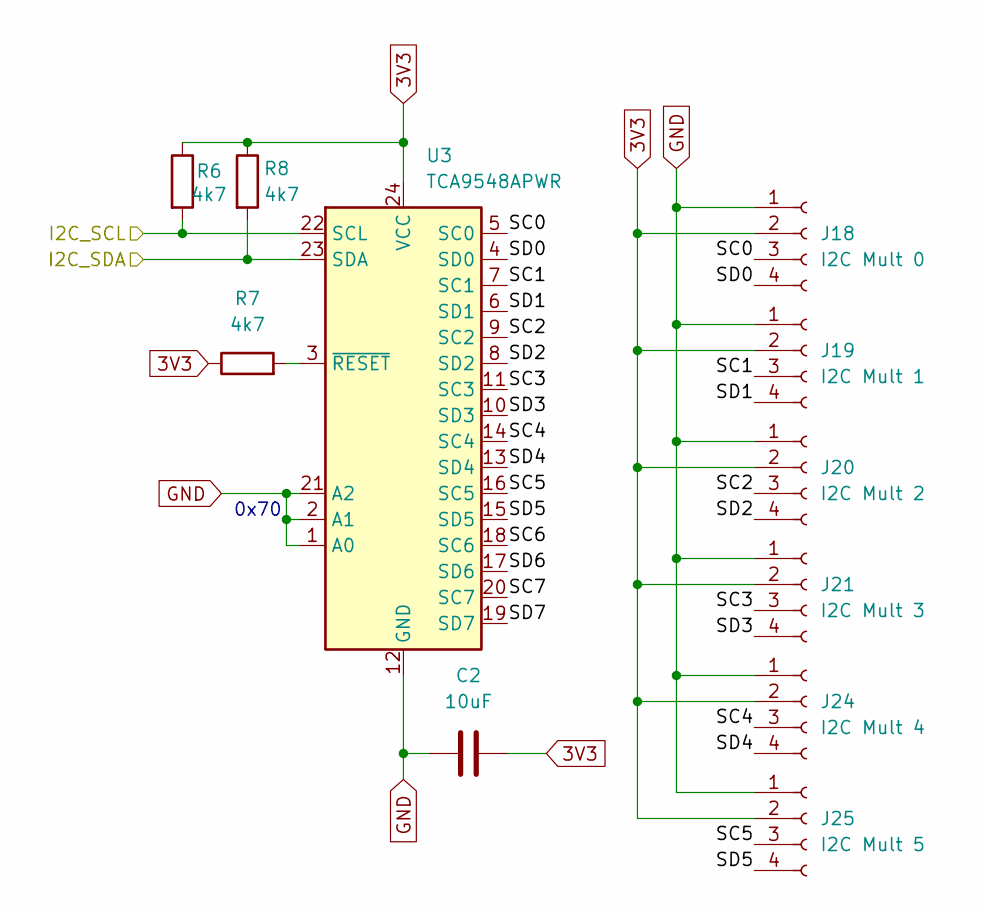
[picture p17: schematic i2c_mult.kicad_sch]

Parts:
C2: 10uF; C_0805_2012Metric_Pad1.18x1.45mm_HandSolder
J18: I2C Mult 0; JST_XH_B4B-XH-A_1x04_P2.50mm_Vertical
J19: I2C Mult 1; JST_XH_B4B-XH-A_1x04_P2.50mm_Vertical
J20: I2C Mult 2; JST_XH_B4B-XH-A_1x04_P2.50mm_Vertical
J21: I2C Mult 3; JST_XH_B4B-XH-A_1x04_P2.50mm_Vertical
J24: I2C Mult 4; JST_XH_B4B-XH-A_1x04_P2.50mm_Vertical
J25: I2C Mult 5; JST_XH_B4B-XH-A_1x04_P2.50mm_Vertical
R6, R7, R8: 4k7; R_0805_2012Metric_Pad1.20x1.40mm_HandSolder
U3: TCA9548APWR; TSSOP-24_4.4x7.8mm_P0.65mm

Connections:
3V3: C2.1, J18.2, J19.2, J20.2, J21.2, J24.2, J25.2, R6.1, R7.1, R8.1, U3.24 (VCC); also elsewhere on the board
/I2C_MULT/I2C_SCL: R6.2, U3.22 (SCL); also elsewhere on the board
/I2C_MULT/I2C_SDA: R8.2, U3.23 (SDA); also elsewhere on the board
/I2C_MULT/SC0: J18.3, U3.5 (SC0)
/I2C_MULT/SC1: J19.3, U3.7 (SC1)
/I2C_MULT/SC2: J20.3, U3.9 (SC2)
/I2C_MULT/SC3: J21.3, U3.11 (SC3)
/I2C_MULT/SC4: J24.3, U3.14 (SC4)
/I2C_MULT/SC5: J25.3, U3.16 (SC5)
/I2C_MULT/SC6: U3.18 (SC6)
/I2C_MULT/SC7: U3.20 (SC7)
/I2C_MULT/SD0: J18.4, U3.4 (SD0)
/I2C_MULT/SD1: J19.4, U3.6 (SD1)
/I2C_MULT/SD2: J20.4, U3.8 (SD2)
/I2C_MULT/SD3: J21.4, U3.10 (SD3)
/I2C_MULT/SD4: J24.4, U3.13 (SD4)
/I2C_MULT/SD5: J25.4, U3.15 (SD5)
/I2C_MULT/SD6: U3.17 (SD6)
/I2C_MULT/SD7: U3.19 (SD7)
GND: C2.2, J18.1, J19.1, J20.1, J21.1, J24.1, J25.1, U3.1 (A0), U3.2 (A1), U3.12 (GND), U3.21 (A2); also elsewhere on the board
unnamed: R7.2, U3.3 (~RESET)

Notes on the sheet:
0x70

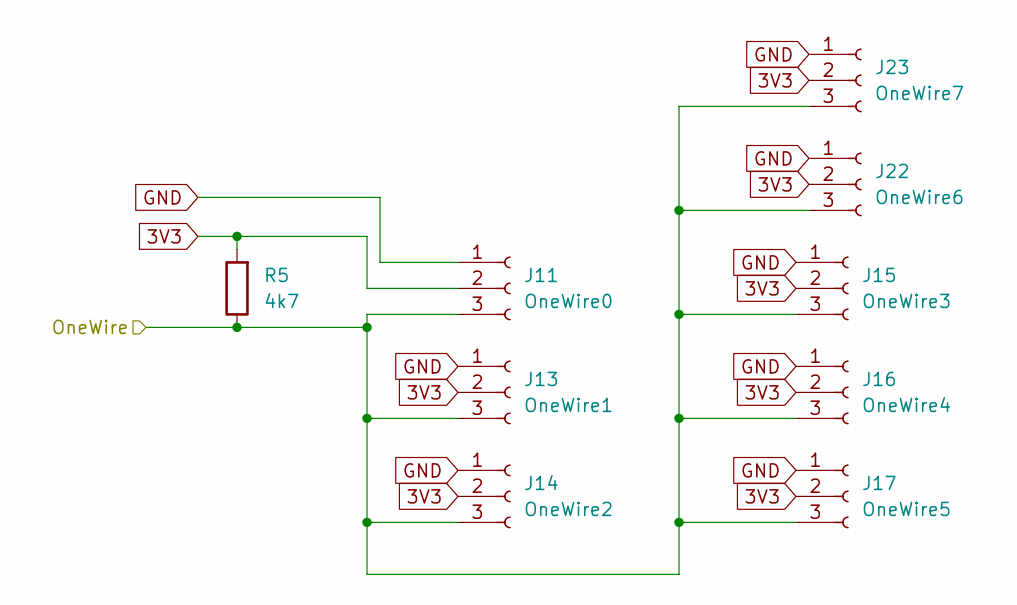
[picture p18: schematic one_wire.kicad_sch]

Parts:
J11: OneWire0; JST_XH_B3B-XH-A_1x03_P2.50mm_Vertical
J13: OneWire1; JST_XH_B3B-XH-A_1x03_P2.50mm_Vertical
J14: OneWire2; JST_XH_B3B-XH-A_1x03_P2.50mm_Vertical
J15: OneWire3; JST_XH_B3B-XH-A_1x03_P2.50mm_Vertical
J16: OneWire4; JST_XH_B3B-XH-A_1x03_P2.50mm_Vertical
J17: OneWire5; JST_XH_B3B-XH-A_1x03_P2.50mm_Vertical
J22: OneWire6; JST_XH_B3B-XH-A_1x03_P2.50mm_Vertical
J23: OneWire7; JST_XH_B3B-XH-A_1x03_P2.50mm_Vertical
R5: 4k7; R_0805_2012Metric_Pad1.20x1.40mm_HandSolder

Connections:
3V3: J11.2, J13.2, J14.2, J15.2, J16.2, J17.2, J22.2, J23.2, R5.2; also elsewhere on the board
/ONE_WIRE/OneWire: J11.3, J13.3, J14.3, J15.3, J16.3, J17.3, J22.3, J23.3, R5.1; also elsewhere on the board
GND: J11.1, J13.1, J14.1, J15.1, J16.1, J17.1, J22.1, J23.1; also elsewhere on the board

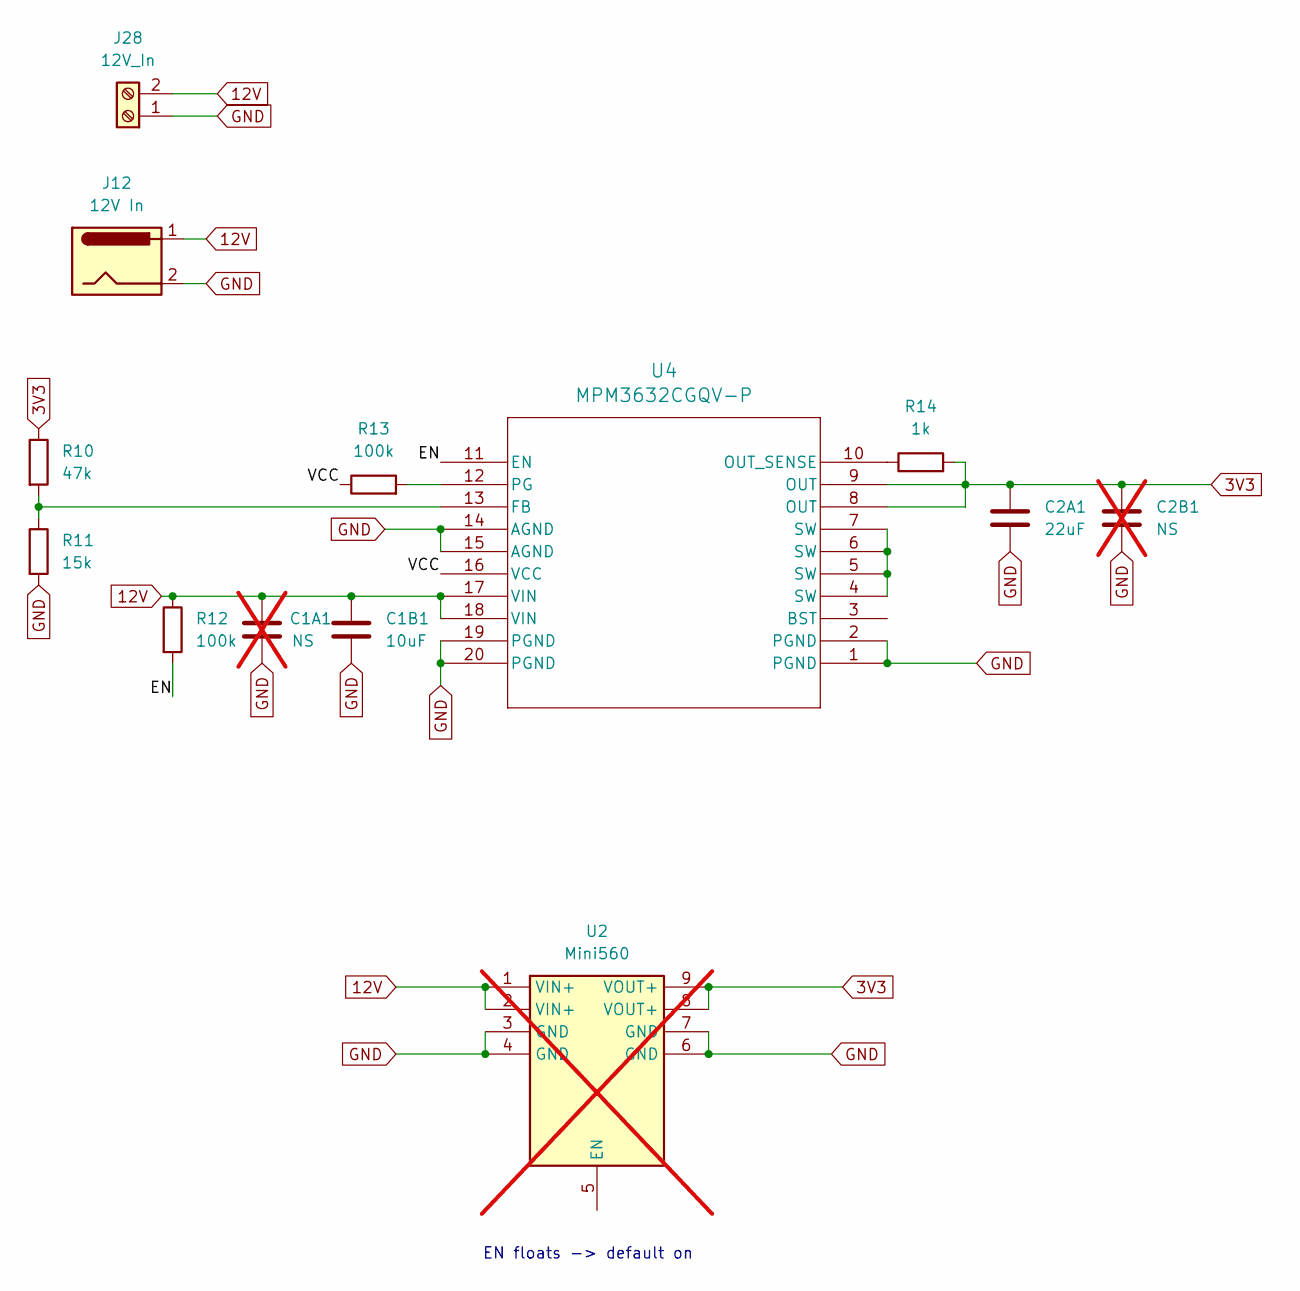
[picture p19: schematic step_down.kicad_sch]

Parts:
C1A1, C2B1: NS; C_1206_3216Metric_Pad1.33x1.80mm_HandSolder; not fitted
C1B1: 10uF; C_1206_3216Metric_Pad1.33x1.80mm_HandSolder
C2A1: 22uF; C_1206_3216Metric_Pad1.33x1.80mm_HandSolder
J12: 12V In; BarrelJack_GCT_DCJ200-10-A_Horizontal
J28: 12V_In; Altech_AK100_1x02_P5.00mm
R10: 47k; R_0603_1608Metric_Pad0.98x0.95mm_HandSolder
R11: 15k; R_0603_1608Metric_Pad0.98x0.95mm_HandSolder
R12, R13: 100k; R_0603_1608Metric_Pad0.98x0.95mm_HandSolder
R14: 1k; R_0805_2012Metric_Pad1.20x1.40mm_HandSolder
U2: Mini560; Manufacturer_Part_Number Mini560; not fitted
U4: MPM3632CGQV-P; QFN3p0x5p0x1p6_MPM3632C_MNP

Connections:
3V3: C2A1.1, C2B1.1, R10.1, R14.2, U2.8 (VOUT+), U2.9 (VOUT+), U4.8 (OUT), U4.9 (OUT); also elsewhere on the board
12V: C1A1.1, C1B1.1, J12.1, J28.2, R12.1, U2.1 (VIN+), U2.2 (VIN+), U4.17 (VIN), U4.18 (VIN); also elsewhere on the board
/STEP_DOWN/EN: R12.2, U4.11 (EN)
/STEP_DOWN/VCC: R13.1, U4.16 (VCC)
GND: C1A1.2, C1B1.2, C2A1.2, C2B1.2, J12.2, J28.1, R11.2, U2.3 (GND), U2.4 (GND), U2.6 (GND), U2.7 (GND), U4.1 (PGND), U4.2 (PGND), U4.14 (AGND), U4.15 (AGND), U4.19 (PGND), U4.20 (PGND); also elsewhere on the board
unnamed: R10.2, R11.1, U4.13 (FB)
unnamed: R14.1, U4.10 (OUT_SENSE)
unnamed: R13.2, U4.12 (PG)
unnamed: U4.4 (SW), U4.5 (SW), U4.6 (SW), U4.7 (SW)

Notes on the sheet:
EN floats -> default on

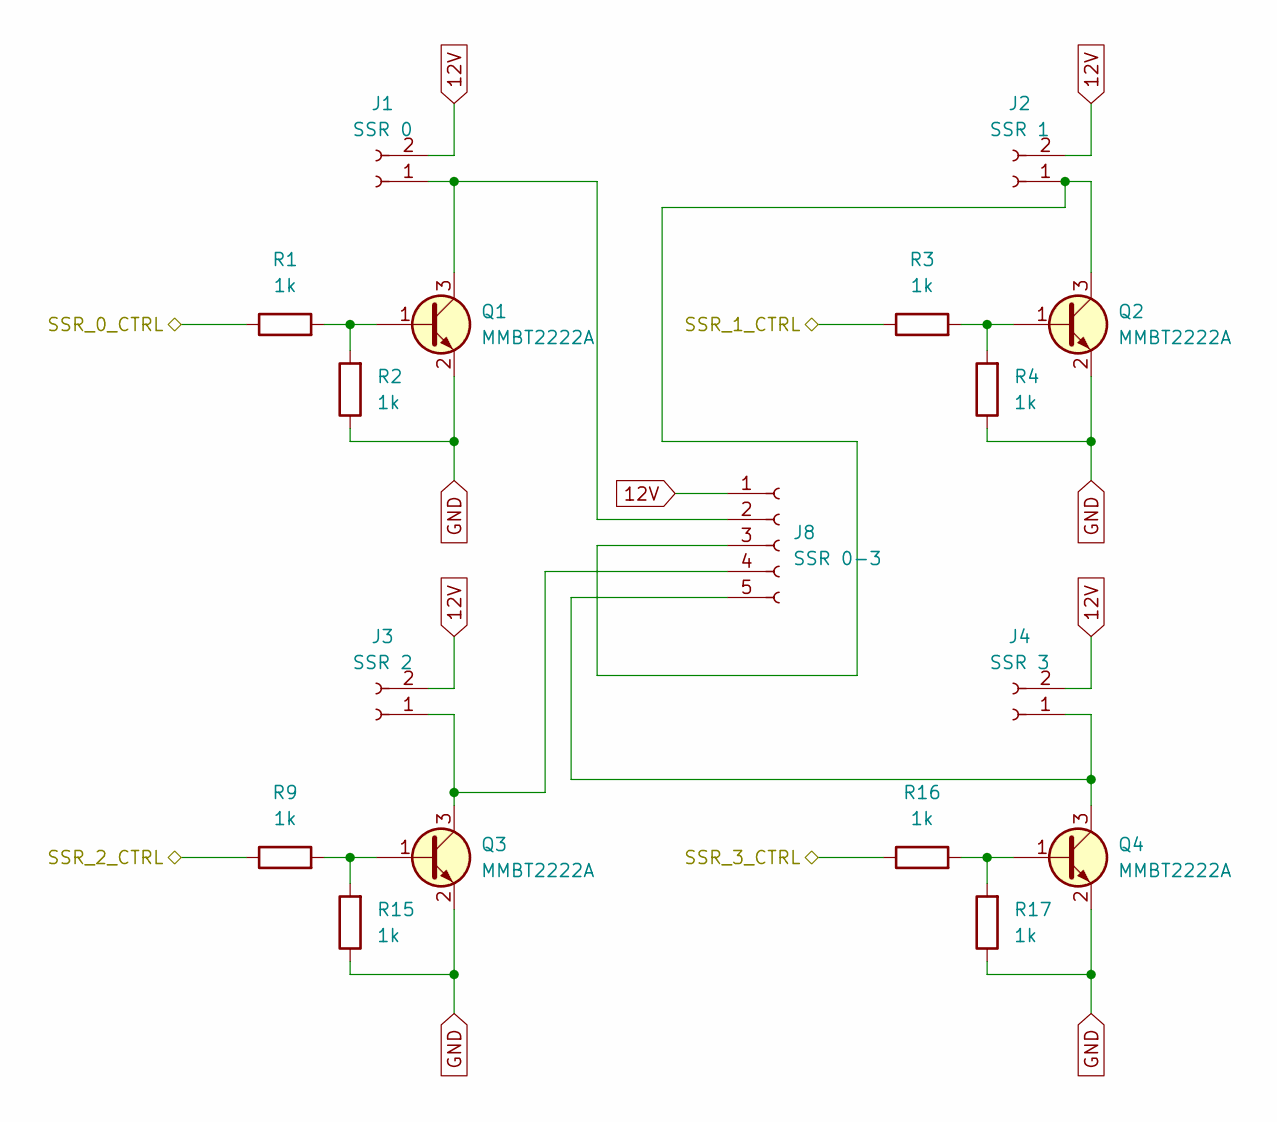
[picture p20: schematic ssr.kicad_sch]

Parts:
J1: SSR 0; JST_XH_B2B-XH-A_1x02_P2.50mm_Vertical
J2: SSR 1; JST_XH_B2B-XH-A_1x02_P2.50mm_Vertical
J3: SSR 2; JST_XH_B2B-XH-A_1x02_P2.50mm_Vertical
J4: SSR 3; JST_XH_B2B-XH-A_1x02_P2.50mm_Vertical
J8: SSR 0-3; JST_XH_B5B-XH-A_1x05_P2.50mm_Vertical
Q1, Q2, Q3, Q4: MMBT2222A; SOT-23
R1, R2, R3, R4, R9, R15, R16, R17: 1k; R_0805_2012Metric_Pad1.20x1.40mm_HandSolder

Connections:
12V: J1.2, J2.2, J3.2, J4.2, J8.1; also elsewhere on the board
/SSR/SSR_0_CTRL: R1.1; also elsewhere on the board
/SSR/SSR_1_CTRL: R3.1; also elsewhere on the board
/SSR/SSR_2_CTRL: R9.1; also elsewhere on the board
/SSR/SSR_3_CTRL: R16.1; also elsewhere on the board
GND: Q1.2 (E), Q2.2 (E), Q3.2 (E), Q4.2 (E), R2.1, R4.1, R15.1, R17.1; also elsewhere on the board
unnamed: J1.1, J8.2, Q1.3 (C)
unnamed: J2.1, J8.3, Q2.3 (C)
unnamed: J3.1, J8.4, Q3.3 (C)
unnamed: J4.1, J8.5, Q4.3 (C)
unnamed: Q1.1 (B), R1.2, R2.2
unnamed: Q2.1 (B), R3.2, R4.2
unnamed: Q3.1 (B), R9.2, R15.2
unnamed: Q4.1 (B), R16.2, R17.2

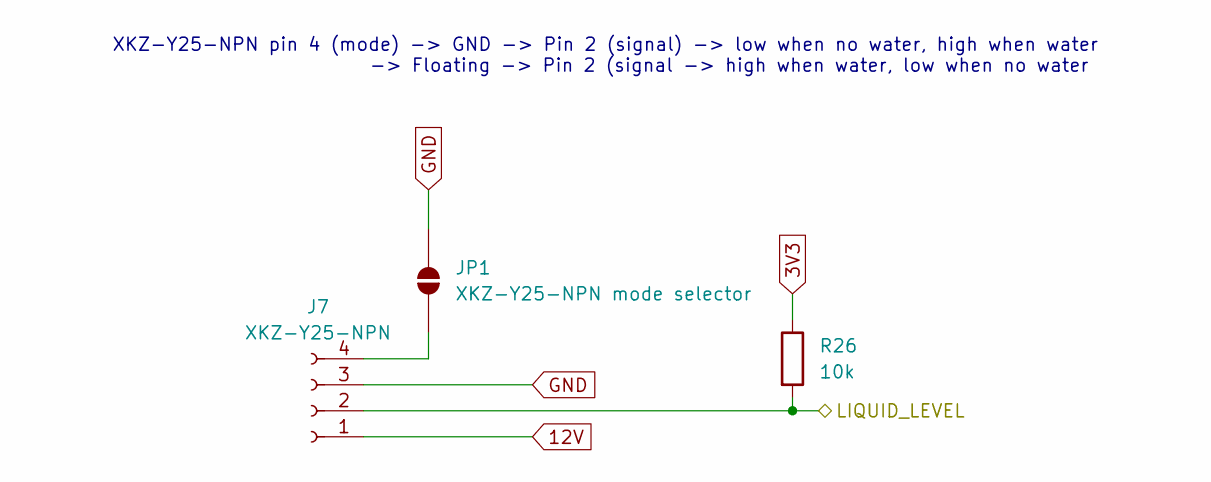
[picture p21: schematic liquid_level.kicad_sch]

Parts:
J7: XKZ-Y25-NPN; JST_XH_B4B-XH-A_1x04_P2.50mm_Vertical
JP1: XKZ-Y25-NPN mode selector; SolderJumper-2_P1.3mm_Open_Pad1.0x1.5mm
R26: 10k; R_0805_2012Metric_Pad1.20x1.40mm_HandSolder

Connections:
3V3: R26.1; also elsewhere on the board
12V: J7.1; also elsewhere on the board
/LIQUID_LEVEL/LIQUID_LEVEL: J7.2, R26.2; also elsewhere on the board
GND: J7.3, JP1.2 (B); also elsewhere on the board
unnamed: J7.4, JP1.1 (A)

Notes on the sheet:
XKZ-Y25-NPN pin 4 (mode) -> GND -> Pin 2 (signal) -> low when no water, high when water -> Floating -> Pin 2 (signal -> high when water, low when no water

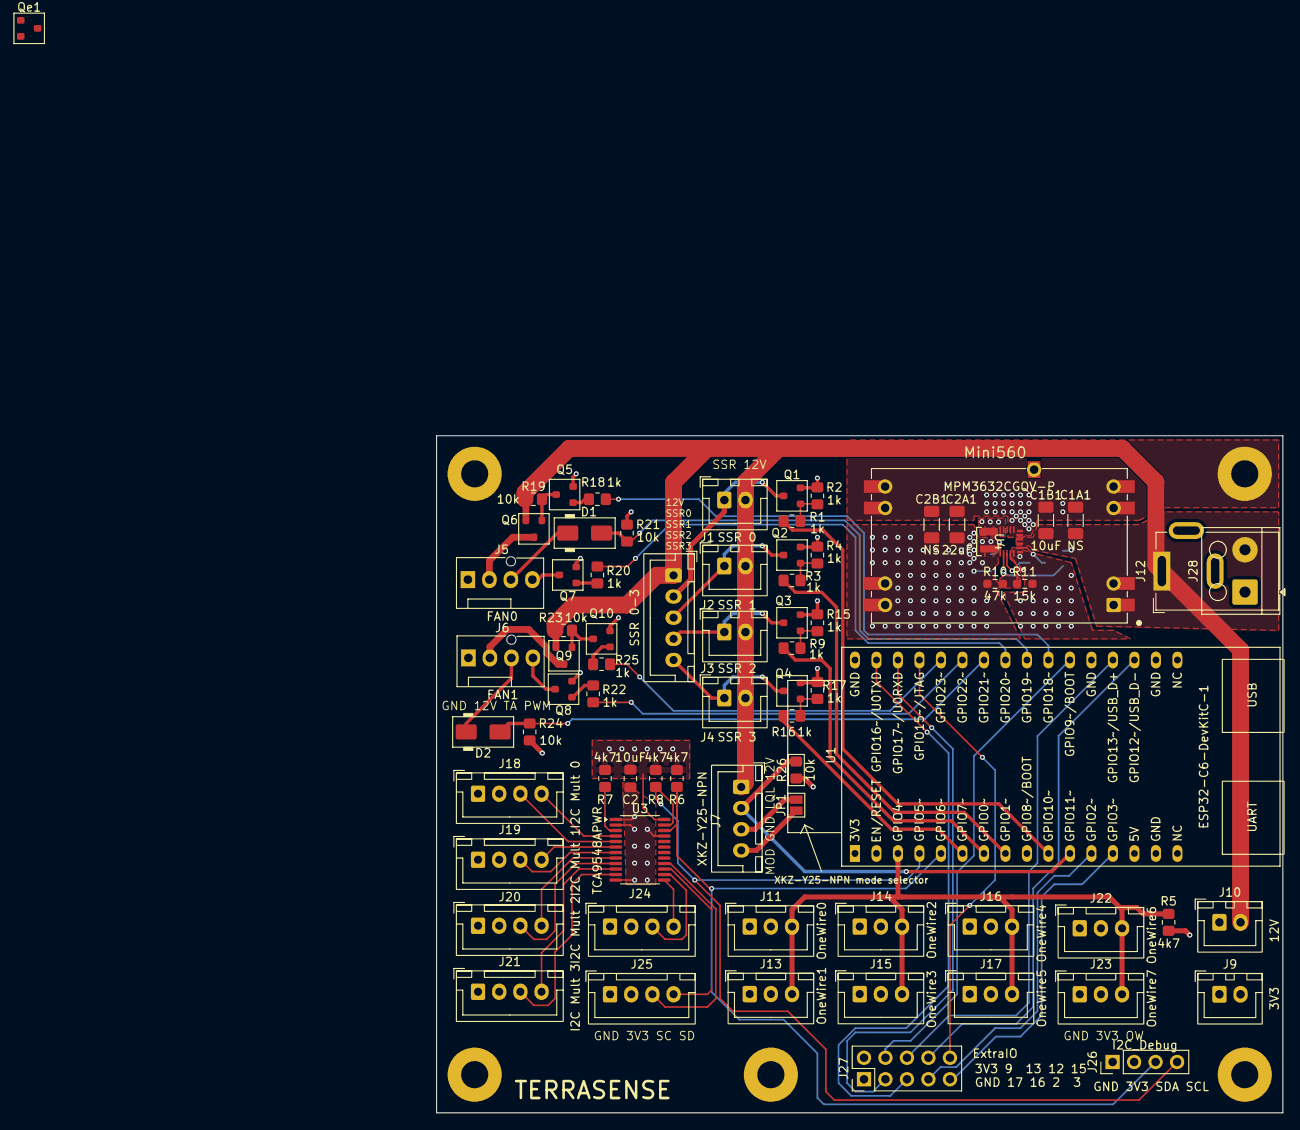
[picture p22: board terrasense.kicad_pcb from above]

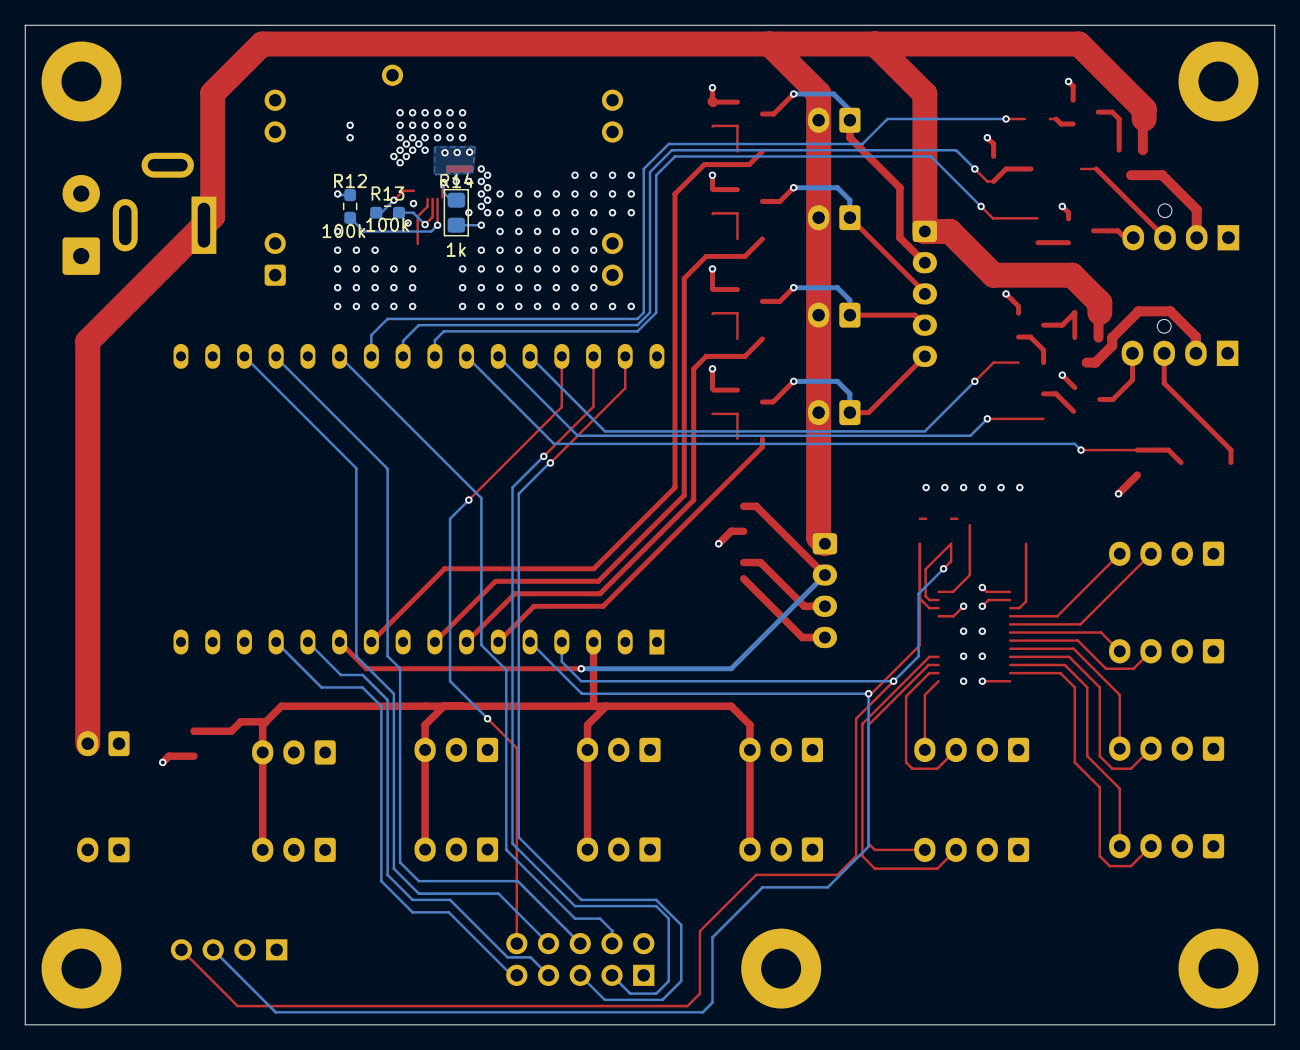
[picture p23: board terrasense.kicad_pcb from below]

Board: 4 copper layers, 100.0 x 80.0 mm, 77 parts (3 on the bottom side), 65 nets.

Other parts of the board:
Qe1: A3401; SOT-23

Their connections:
12V: Qe1.2 (S); also elsewhere on the board
unnamed 51: Qe1.3 (D); also elsewhere on the board
unnamed 63: Qe1.1 (G); also elsewhere on the board

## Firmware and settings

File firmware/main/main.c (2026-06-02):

#include <stdio.h>
#include <string.h>
#include "freertos/FreeRTOS.h"
#include "freertos/task.h"
#include "nvs_flash.h"

#include "sys_config.h"
#include "sys_utils.h"
#include "sys_led.h" 
#include "sys_ota.h" 

#include "net_core.h"
#include "net_mqtt.h" 

#include "sensors.h"  
#include "actors.h"
#include "app_logic.h"

sys_debug_led_t builtin_status_led;

/**
 * We can only have one global mqtt callback function. Chose to reside in main. Main only handles OTA callback, 
 * rest is forwarded to app logic.
 */
static void mqtt_router_callback(const char *topic, const char *payload)
{
    if (strstr(topic, MQTT_OTA_SUBTOPIC) != NULL) {
        SYS_LOG("OTA Command Received!");
        sys_ota_start(&builtin_status_led, payload);
        return;
    }
    app_logic_handle_mqtt(topic, payload);
}

void app_main(void)
{
    vTaskDelay(pdMS_TO_TICKS(500)); 
    SYS_LOG("=========================================");
    SYS_LOG("Terrasense Booting!");
    SYS_LOG("=========================================");

#ifdef CONFIG_TERRARIUM_CRAWL_CAY
    SYS_LOG("Running configuration: Terrarium Crawl Cay");
#else
    SYS_LOG("Running configuration: Terrarium Test");
#endif

    //* ----- Core System Initialization -----
    sys_led_init(&builtin_status_led); 
    sys_led_set_state(&builtin_status_led, SYS_LED_STATE_BOOTING);
    esp_err_t ret = nvs_flash_init();
    if (ret == ESP_ERR_NVS_NO_FREE_PAGES || ret == ESP_ERR_NVS_NEW_VERSION_FOUND) {
        ESP_ERROR_CHECK(nvs_flash_erase());
        ret = nvs_flash_init();
    }
    SYS_ERR_CHECK(ret, "Failed to initialize NVS");

    //* ----- Hardware Peripherals Initialization -----
    SYS_LOG("Initializing Hardware Peripherals...");
    sensors_init(&builtin_status_led);
    actors_init(&builtin_status_led);

    //* ----- Network Initialization -----
    SYS_LOG("Initializing Networking Stack...");
    net_core_init(&builtin_status_led);
    // adding some delays to ensure we have a clean startup
    vTaskDelay(pdMS_TO_TICKS(5000));
    net_mqtt_init(&builtin_status_led, mqtt_router_callback);
    net_mqtt_start();
    vTaskDelay(pdMS_TO_TICKS(2000)); 
    //* Subscribe to OTA command topic
    net_mqtt_subscribe(MQTT_OTA_SUBTOPIC, 1);

    sys_led_set_state(&builtin_status_led, SYS_LED_STATE_OK_DAY);
    SYS_LOG("Boot complete. Entering system monitor.");

    //* ----- Application Logic -----
    app_logic_init(&builtin_status_led);

    //* ----- The Main Loop (System Monitor) -----
    uint32_t uptime_minutes = 0;
    while (1) {

        size_t heap = esp_get_free_heap_size();
        if (heap >= 1024 * 1024) {
            SYS_LOG("System Uptime: %lu minutes | Free Heap: %.2f MB", uptime_minutes, heap / (1024.0 * 1024.0));
        } else if (heap >= 1024) {
            SYS_LOG("System Uptime: %lu minutes | Free Heap: %.2f KB", uptime_minutes, heap / 1024.0);
        } else {
            SYS_LOG("System Uptime: %lu minutes | Free Heap: %u bytes", uptime_minutes, (unsigned int)heap);
        }
        uptime_minutes++;
        vTaskDelay(pdMS_TO_TICKS(1 * MINUTE));
    }
}

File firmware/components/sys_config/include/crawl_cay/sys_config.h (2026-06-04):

// components/sys_config/include/sys_config.h
#pragma once
#include "sensors.h"
#include "actors.h"

//* ********************************* */
//* ***** General Configurations **** */
//* ********************************* */
// using ms sleep function pdMS_TO_TICKS()
#define SECOND          1000
#define MINUTE          60 * SECOND
#define HOUR            60 * MINUTE

//* --- Debug Configs ---
#define SYS_LED_DEBUG_MODE_ENABLED  1



//* ********************************* */
//* ****** MQTT Configurations ****** */
//* ********************************* */
#define MQTT_DOMAIN_PREFIX  "terrasense" 
#define TERRARIUM_ID        "terrarium_crawl_cay"
#define MQTT_BASE_TOPIC     MQTT_DOMAIN_PREFIX "/" TERRARIUM_ID

#define MQTT_HASS_AUTODISCOVERY_TOPIC(component, device_id)     "homeassistant/" component "/" MQTT_DOMAIN_PREFIX "-" TERRARIUM_ID "-" device_id "/config"
#define MQTT_STATE_TOPIC(component, device_id)                  MQTT_BASE_TOPIC "/" component "/" device_id "/state"
#define MQTT_COMMAND_TOPIC(component, device_id)                MQTT_BASE_TOPIC "/" component "/" device_id "/command"
#define MQTT_AVAILABILITY_TOPIC                                 MQTT_BASE_TOPIC "/status"

#define MQTT_OTA_SUBTOPIC   "cmd/update"


//* ********************************* */
//* ***** Sensor Configurations ***** */
//* ********************************* */
#define SENSOR_FETCHING_INTERVAL            2 * SECOND
#define SENSOR_LOG_INTERVAL                 10 * SECOND
#define SENSOR_DATA_PUBLISH_INTERVAL        10 * SECOND
#define CONTROL_LOOP_INTERVAL               5 * SECOND

//* --- Sensor Pins ---
#define ONEWIRE_BUS_GPIO    4
#define I2C_MASTER_PORT     0 
#define I2C_SDA_GPIO        5 
#define I2C_SCL_GPIO        6
#define SHT35_I2C_ADDR      0x44
#define MUX_I2C_ADDRESS     0x70
#define BINARY_SENSOR_GPIO  11


//* --- DS18B20 Sensor Configurations ---
// Set to 1 to enable DS18B20 sensors, 0 to disable entirely
#define HARDWARE_DS18B20_ENABLED 1
#if HARDWARE_DS18B20_ENABLED
//! ADHERE TO NAMING SCHEME FROM mqtt_namingscheme.md

static const ds18b20_target_t HARDWARE_DS18B20_CONFIG[] = {
    { .name = "Far Left", .mqtt_device_id = "far_left", .rom_address = 0x6B08225467CF0328 },
    { .name = "Ground", .mqtt_device_id = "ground", .rom_address = 0x48082254936BE028 },
    { .name = "Far Right", .mqtt_device_id = "far_right", .rom_address = 0xD707226171338E28 },
    { .name = "Right Platform", .mqtt_device_id = "right_platform", .rom_address = 0x930822547953C728 },
    { .name = "Left Platform", .mqtt_device_id = "left_platform", .rom_address = 0x4A0922537AB94C28 },
    { .name = "Heatlamp", .mqtt_device_id = "heatlamp", .rom_address = 0x133C6CF64930E728 }
};

// The compiler counts how many DS18B20 sensors we have, need to know the size for creating correct sensor_data_t struct
#define HARDWARE_DS18B20_COUNT (sizeof(HARDWARE_DS18B20_CONFIG) / sizeof(HARDWARE_DS18B20_CONFIG[0]))
#else
#define HARDWARE_DS18B20_COUNT 0
#endif

#define HEATLAMP_DS18B20_NAME "Heatlamp"
#define RIGHT_PLATFORM_DS18B20_NAME "Right Platform"
#define MAXIMUM_HEATLAMP_TEMP 43

//* --- SHT3X / FS304 Sensor Configurations ---
// Set to 1 to enable SHT35 sensors, 0 to disable
#define HARDWARE_SHT3X_ENABLED 1
#if HARDWARE_SHT3X_ENABLED
static const sht3x_target_t HARDWARE_SHT3X_CONFIG[] = {
    { .name = "Center", .mqtt_device_id = "center", .mux_channel = 0 },
    // { .name = "SHT35 Hot Side", .mqtt_device_id = "sht35_hot", .mux_channel = 1 },
};
#define HARDWARE_SHT3X_COUNT (sizeof(HARDWARE_SHT3X_CONFIG) / sizeof(HARDWARE_SHT3X_CONFIG[0]))
#else
#define HARDWARE_SHT3X_COUNT 0
#endif

//* --- Binary Sensor Configurations ---
// Set to 1 to enable Binary sensors, 0 to disable
#define HARDWARE_BINARY_ENABLED 1
#if HARDWARE_BINARY_ENABLED
static const binary_sensor_target_t HARDWARE_BINARY_CONFIG[] = {
    { .name = "Tank Status", .mqtt_device_id = "liquid_level_sensor", .gpio_pin = BINARY_SENSOR_GPIO, .invert_logic = true },
};
#define HARDWARE_BINARY_COUNT (sizeof(HARDWARE_BINARY_CONFIG) / sizeof(HARDWARE_BINARY_CONFIG[0]))
#else
#define HARDWARE_BINARY_COUNT 0
#endif


//* ********************************* */
//* ***** Actuator Configurations *** */
//* ********************************* */

//* --- SSR Control Pins ---

#define RELAY_0_GPIO  10
#define RELAY_1_GPIO  1
#define RELAY_2_GPIO  0
#define SSR_RELAY_GPIO  7
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

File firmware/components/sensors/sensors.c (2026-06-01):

#include "freertos/FreeRTOS.h"
#include "freertos/task.h"
#include "freertos/semphr.h"
#include "sys_utils.h"
#include "sys_config.h"

#include "sensors.h"
#include "sensor_ds18b20.h"
#include "sensor_sht3x.h"
#include "sensor_binary.h"
#include "i2cdev.h"

static sensor_data_t current_sensor_data;
static SemaphoreHandle_t sensor_mutex = NULL;
static sys_debug_led_t *status_led = NULL;

/**
 * This is a background task fetching all the sensor values that are available and storing them in current_sensor_data. 
 * current_sensor_data is protected by sensor_mutex. 
 */
static void sensor_polling_task(void *pvParameter)
{
    SYS_LOG("Sensor polling task started.");
    
#if HARDWARE_DS18B20_ENABLED
    float ds18b20_temp_buffer[SENSOR_DS18B20_COMPONENT_MAX_CAPACITY];
#endif
#if HARDWARE_SHT3X_ENABLED
    float sht3x_temp_buffer[SENSOR_SHT3X_COMPONENT_MAX_CAPACITY];
    float sht3x_hum_buffer[SENSOR_SHT3X_COMPONENT_MAX_CAPACITY];
#endif
#if HARDWARE_BINARY_ENABLED
    bool binary_buffer[SENSOR_BINARY_COMPONENT_MAX_CAPACITY];
#endif

    while (1) {
#if HARDWARE_DS18B20_ENABLED
        sensor_ds18b20_read(ds18b20_temp_buffer);
#endif
#if HARDWARE_SHT3X_ENABLED
        sensor_sht3x_read(sht3x_temp_buffer, sht3x_hum_buffer);
#endif
#if HARDWARE_BINARY_ENABLED
        sensor_binary_read(binary_buffer);
#endif

        if (xSemaphoreTake(sensor_mutex, portMAX_DELAY) == pdTRUE) {
#if HARDWARE_DS18B20_ENABLED
            for (int i = 0; i < HARDWARE_DS18B20_COUNT; i++) {
                current_sensor_data.ds18b20_temps[i] = ds18b20_temp_buffer[i];
            }
#endif
#if HARDWARE_SHT3X_ENABLED
            for (int i = 0; i < HARDWARE_SHT3X_COUNT; i++) {
                current_sensor_data.sht3x_temps[i] = sht3x_temp_buffer[i];
                current_sensor_data.sht3x_hums[i]  = sht3x_hum_buffer[i];
            }
#endif
#if HARDWARE_BINARY_ENABLED
            for (int i = 0; i < HARDWARE_BINARY_COUNT; i++) {
                current_sensor_data.binary_states[i] = binary_buffer[i];
            }
#endif
            xSemaphoreGive(sensor_mutex);
        }
        
        vTaskDelay(pdMS_TO_TICKS(SENSOR_FETCHING_INTERVAL));
    }
}

void sensors_init(sys_debug_led_t *debug_led)
{
    status_led = debug_led;
    // Initialize the shared I2C device library first
    ESP_ERROR_CHECK(i2cdev_init());
#if HARDWARE_DS18B20_ENABLED
    if (HARDWARE_DS18B20_COUNT > SENSOR_DS18B20_COMPONENT_MAX_CAPACITY) {
        SYS_LOG_ERR("Configured DS18B20 sensors exceed max capacity!");
        configASSERT(0);
    }
    for (int i = 0; i < SENSOR_DS18B20_COMPONENT_MAX_CAPACITY; i++) {
        current_sensor_data.ds18b20_temps[i] = SENSOR_VALUE_INVALID;
    }
    sensor_ds18b20_init(ONEWIRE_BUS_GPIO, HARDWARE_DS18B20_CONFIG, HARDWARE_DS18B20_COUNT, debug_led);
#endif
#if HARDWARE_SHT3X_ENABLED
    if (HARDWARE_SHT3X_COUNT > SENSOR_SHT3X_COMPONENT_MAX_CAPACITY) {
        SYS_LOG_ERR("Configured SHT3X sensors exceed max capacity!");
        configASSERT(0);
    }
    for (int i = 0; i < SENSOR_SHT3X_COMPONENT_MAX_CAPACITY; i++) {
        current_sensor_data.sht3x_temps[i] = SENSOR_VALUE_INVALID;
        current_sensor_data.sht3x_hums[i]  = SENSOR_VALUE_INVALID;
    }
    sensor_sht3x_init(I2C_MASTER_PORT, I2C_SDA_GPIO, I2C_SCL_GPIO, HARDWARE_SHT3X_CONFIG, HARDWARE_SHT3X_COUNT, debug_led);
#endif
#if HARDWARE_BINARY_ENABLED
    if (HARDWARE_BINARY_COUNT > SENSOR_BINARY_COMPONENT_MAX_CAPACITY) {
        SYS_LOG_ERR("Configured Binary sensors exceed max capacity!");
        configASSERT(0);
    }
    for (int i = 0; i < SENSOR_BINARY_COMPONENT_MAX_CAPACITY; i++) {
        current_sensor_data.binary_states[i] = false;
    }
    sensor_binary_init(debug_led);
#endif
    sensor_mutex = xSemaphoreCreateMutex();
    xTaskCreate(sensor_polling_task, "sensor_task", 4096, NULL, 5, NULL);
}

bool sensors_get_data(sensor_data_t *out_data)
{
    if (sensor_mutex == NULL || out_data == NULL) return false;

    // Try to lock the mutex for up to 100ms
    if (xSemaphoreTake(sensor_mutex, pdMS_TO_TICKS(100)) == pdTRUE) {
        *out_data = current_sensor_data; // Copy the data safely
        xSemaphoreGive(sensor_mutex);
        return true;
    }
    
    return false;
}

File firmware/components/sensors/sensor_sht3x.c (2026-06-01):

#include "freertos/FreeRTOS.h"
#include "freertos/task.h"
#include "sys_utils.h"
#include "sys_config.h"
#include "sensor_sht3x.h"
#include "sht3x.h"
#include "tca9548.h" // Added the MUX library
#include <string.h>


static sys_debug_led_t *status_led = NULL;
static sht3x_t sht3x_handles[SENSOR_SHT3X_COMPONENT_MAX_CAPACITY];
static bool sht3x_active[SENSOR_SHT3X_COMPONENT_MAX_CAPACITY] = {false};
static i2c_dev_t mux_dev;

static int configured_sht3x_count = 0;
static const sht3x_target_t *sht_configs = NULL;

void sensor_sht3x_init(int i2c_port, int sda_pin, int scl_pin, const sht3x_target_t *targets, int target_count, sys_debug_led_t *debug_led)
{
    status_led = debug_led;
    configured_sht3x_count = target_count;
    sht_configs = targets;
    
    SYS_LOG("Initializing SHT3X Worker and MUX. Configuring %d sensors...", target_count);

    // initializing multiplexer
    memset(&mux_dev, 0, sizeof(i2c_dev_t));
    esp_err_t mux_res = tca9548_init_desc(&mux_dev, MUX_I2C_ADDRESS, i2c_port, sda_pin, scl_pin);
    if (mux_res != ESP_OK) {
        SYS_LOG_ERR("Failed to initialize TCA9548A Multiplexer descriptor!");
        return; 
    }

    for (int i = 0; i < target_count; i++) {
        memset(&sht3x_handles[i], 0, sizeof(sht3x_t));
        
        ESP_ERROR_CHECK(sht3x_init_desc(&sht3x_handles[i], SHT35_I2C_ADDR, i2c_port, sda_pin, scl_pin));
        
        SYS_LOG("Worker: Connecting MUX to channel %d for '%s'", targets[i].mux_channel, targets[i].name);
        
        esp_err_t channel_res = tca9548_set_channels(&mux_dev, (1 << targets[i].mux_channel));
        
        if (channel_res != ESP_OK) {
            SYS_LOG_ERR("Failed to switch MUX to channel %d. Skipping sensor.", targets[i].mux_channel);
            sht3x_active[i] = false;
            continue;
        }

        esp_err_t res = sht3x_init(&sht3x_handles[i]);
        if (res == ESP_OK) {
            sht3x_active[i] = true;
            SYS_LOG("Worker: Successfully Bound '%s' to Index %d", targets[i].name, i);
        } else {
            sht3x_active[i] = false;
            SYS_LOG_ERR("Worker: Failed to initialize '%s' (Mux %d). Check wiring!", targets[i].name, targets[i].mux_channel);
        }
    }
}

void sensor_sht3x_read(float *output_temps, float *output_hums)
{
    for (int i = 0; i < configured_sht3x_count; i++) {
        if (!sht3x_active[i]) {
            output_temps[i] = SENSOR_VALUE_INVALID;
            output_hums[i]  = SENSOR_VALUE_INVALID;
            continue;
        }

        esp_err_t mux_res = tca9548_set_channels(&mux_dev, (1 << sht_configs[i].mux_channel));
        
        if (mux_res != ESP_OK) {
            output_temps[i] = SENSOR_VALUE_INVALID;
            output_hums[i]  = SENSOR_VALUE_INVALID;
            continue; 
        }

        float t, h;
        esp_err_t res = sht3x_measure(&sht3x_handles[i], &t, &h);
        
        if (res == ESP_OK) {
            output_temps[i] = t;
            output_hums[i]  = h;
        } else {
            output_temps[i] = SENSOR_VALUE_INVALID;
            output_hums[i]  = SENSOR_VALUE_INVALID;
        }
    }
}

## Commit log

2026-04-27 init pcb v0.1
    [fan.kicad_sch, i2c_mult.kicad_sch, liquid_level.kicad_sch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]
2026-04-29 first init of esp-idf firmware, wifi and mqtt are working already
    [partitions.csv]
2026-04-29 update default to use correct esp board
2026-05-07 basic ds18b20 integration, including mutex protected sensor values polling in sensor.c
2026-05-07 cleanup using dedicated sys_config.h for hardware and pin configurations
2026-05-11 damn huge mqtt cleanup. logic split up into app_logic. Hass autodiscovery and sensor data publish handled by app_logic. OTA still works
2026-05-11 compile-time opt-in flag for DS18B20 sensor
2026-05-13 single SHT35 supported, TODO: need I2C multiplexer support. HASS autodiscovery supports multiple entities through unique id
2026-05-18 Added I2C integration with TCA9548A MUX
2026-05-18 binary sensor integration
2026-05-19 basic gpio switch for SSR with subscribe example
2026-05-20 added debug led for sensor component
2026-05-20 slight builtin led cleanup
2026-05-27 GRB and RGB switching
2026-05-27 fan integration for 3pin and 4pin fan, including RPM for 4pin fans. all with HA autodiscovery
2026-05-27 added print for dns server
2026-05-27 small config changes for 8mb esp32c6 and enabled https for ota
2026-06-01 sensor component cleanup
2026-06-02 renamed a folder
    [partitions.csv]
2026-06-02 update pcb with ordered pcb
    [fan.kicad_sch, high_volt_switch.kicad_pcb, high_volt_switch.kicad_sch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]
2026-06-02 added system error sensor to autodiscovery for text based error messages and fixed a typo for setup detection
    [app_logic_crawl_cay.c, app_logic_test.c, main.c]
2026-06-03 small fixes in app_logic
    [app_logic_crawl_cay.c]
2026-06-04 made uique id terrarium specific; added a small delay during auto discovery to ensure everything is received by the broker
    [sys_config.h]
2026-06-05 added cad files for a colleague
    [Box.ipt, Box_Assembly.iam, Double_Steckdose.ipt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]
